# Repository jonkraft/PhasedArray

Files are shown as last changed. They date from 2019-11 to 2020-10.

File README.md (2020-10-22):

# PhasedArray
(GNU Radio 2020 Workshop presentation can be viewed here:  https://youtu.be/0hnWfTvETcU)

Phased array beamformers are very powerful! And they find applications in 5G MIMO, FMCW radar, and satellite communications. But their underlying principles and issues can be hard to intuitively grasp. But with the instructions and explanations here, you can build an easy to use system that allows you to experience the underlying math and principles of beamformers.  With this setup, you'll track an RF source, plot its beam characteristics and learn of the features integrated into modern beamformer ICs. It is a hands-on way to learn about steering angle, beam width, null locations, beam tapering, grating lobes, and beam squint.  

To get started, first read the "Phased Array Lab Build Your Own" document.  Then peruse the "Phased Array Lab" document to see what we'll be learning.  After that, please try it out and build your own.  Seeing and manipulating the beam first hand is much more informative and educational then just seeing the equations or the slides I provide of what the beam should look like.  Build it, play with it, and you'll learn a ton about this very powerful concept.

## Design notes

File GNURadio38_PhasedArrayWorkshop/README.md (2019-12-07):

These are the GNUradio flowgraphs to run the lab on.  They work great on a Raspberry Pi 3B+.  But I would recommend that you first download the entire Raspberry Pi SD card here:
https://download.analog.com/phased-array-lab/raspi.7z

It's a big file (3GB), so it'll take a while to download.  Then unzip using using 7-Zip.  Then burn it to a 32 GB (not 16, not >32GB!) micro SD card using Win32 Disk Imager (or some equivalent program).  Then place that micro SD card into your Raspberry Pi, and you will be up and running!  No other install or downloads are required.  

However, the GNU Radio files on that image may not be them most up to date.  So it's always a good idea to check the version in this "PhasedArrayLab_GNURadio" folder and make sure you have the latest.

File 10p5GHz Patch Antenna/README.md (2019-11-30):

This is an 8 element 10.5GHz Patch Antenna designed by Ozan Gurbuz.  It is for instructional or hobby use only.

This antenna can be ordered directly from PCBWAY by following this link:

  https://www.pcbway.com/project/shareproject/10_5GHz__X_Band__Patch_Antenna.html

The edge mount 50 ohm SMA connector can be ordered here:

  https://www.digikey.com/product-detail/en/BU-1420701851/314-1703-ND/9950117/?itemSeq=310517966

PCB Fabrication options are:

  Size :	171 x 60 mm
  
  Layers :	4 Layers
  
  Material :	FR-4 TG150	
  
  Thickness :	1.6 mm	
  
  Min Track/Spacing :	6/6mil
  
  Min Hole Size :	0.3	
  
  Gold fingers :	No
  
  Surface Finish :	HASL lead free	
  
  Via Process :	Tenting vias
  
  Finished Copper :	1 oz Cu (Inner Copper:1 oz)

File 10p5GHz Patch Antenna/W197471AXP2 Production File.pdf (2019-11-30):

CAM350/DFMSTREAM V 12.1 : Sun Nov 24 22:21:44 2019 - (Untitled) : BRD_OUT.gbr

CAM350/DFMSTREAM V 12.1 : Sun Nov 24 22:21:44 2019 - (Untitled) : L1_top.gbr

CAM350/DFMSTREAM V 12.1 : Sun Nov 24 22:21:44 2019 - (Untitled) : L2_inner.gbr

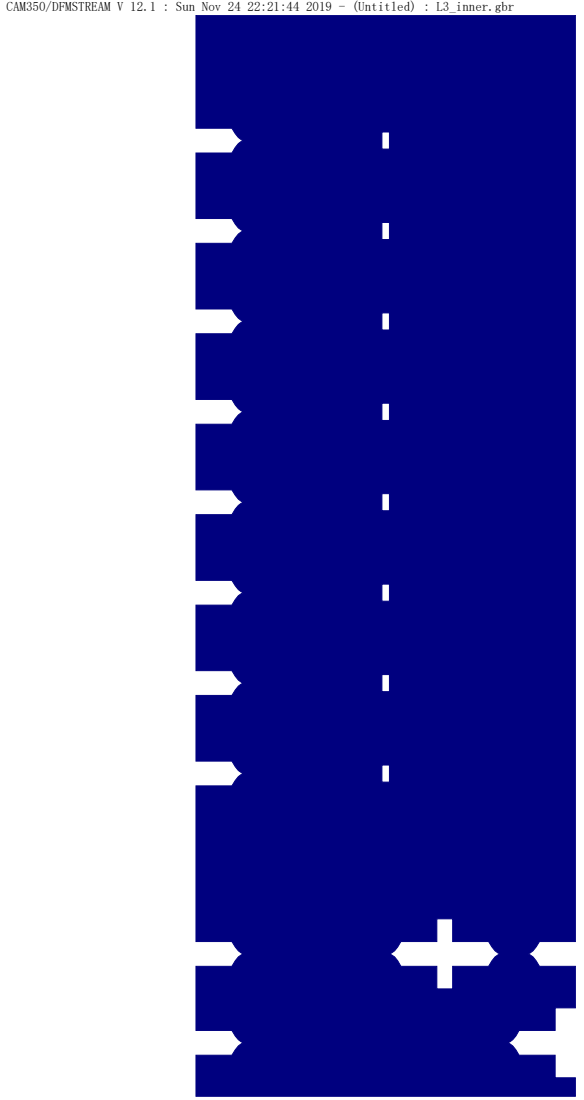
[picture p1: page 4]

CAM350/DFMSTREAM V 12.1 : Sun Nov 24 22:21:44 2019 - (Untitled) : L3_inner.gbr

CAM350/DFMSTREAM V 12.1 : Sun Nov 24 22:21:44 2019 - (Untitled) : L4_bot.gbr

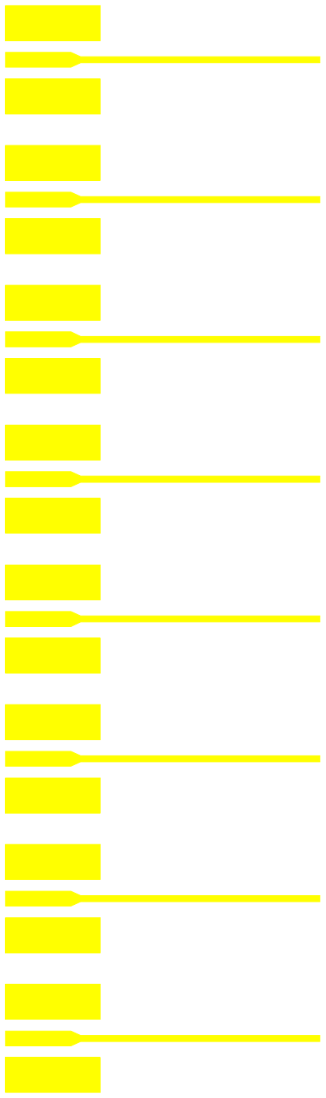
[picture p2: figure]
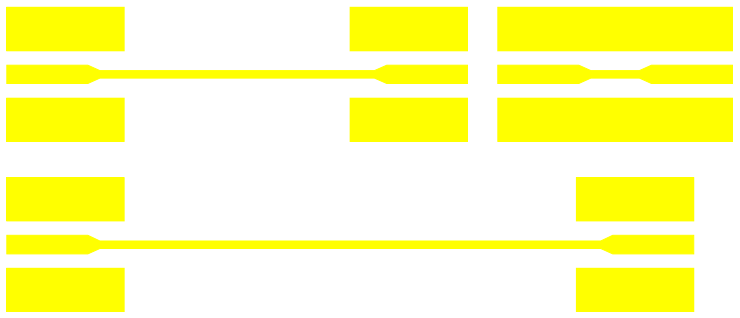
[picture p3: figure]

CAM350/DFMSTREAM V 12.1 : Sun Nov 24 22:21:44 2019 - (Untitled) : NPTH.gbr

CAM350/DFMSTREAM V 12.1 : Sun Nov 24 22:21:44 2019 - (Untitled) : SM_L1_top.gbr

CAM350/DFMSTREAM V 12.1 : Sun Nov 24 22:21:44 2019 - (Untitled) : SM_L4_bot.gbr

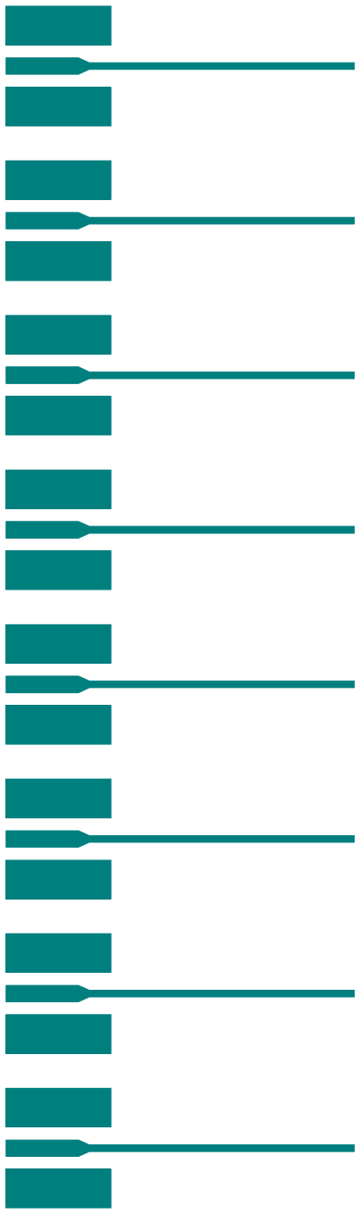
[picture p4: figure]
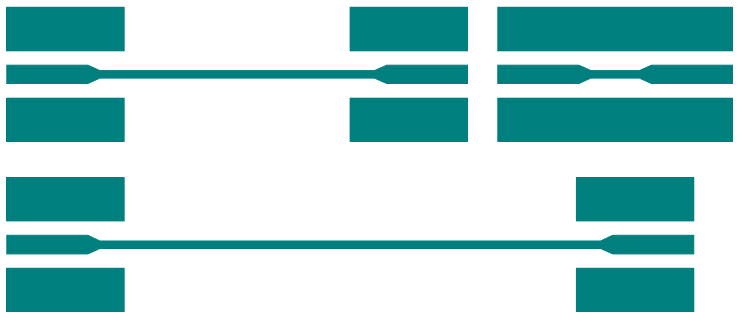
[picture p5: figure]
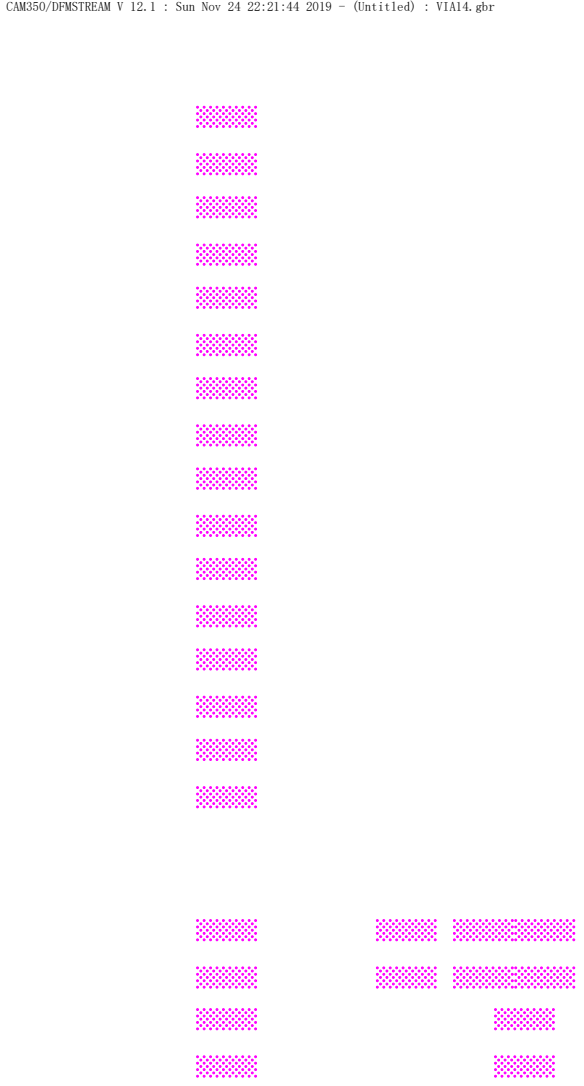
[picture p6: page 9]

CAM350/DFMSTREAM V 12.1 : Sun Nov 24 22:21:44 2019 - (Untitled) : VIA14.gbr

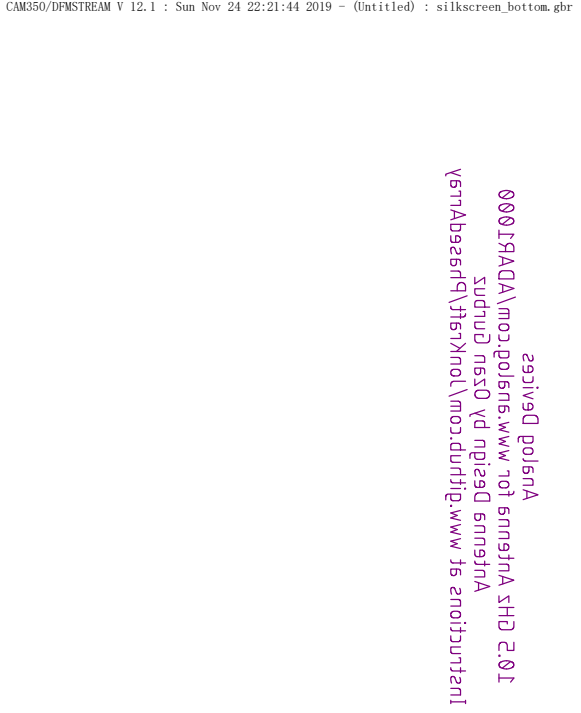
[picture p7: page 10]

CAM350/DFMSTREAM V 12.1 : Sun Nov 24 22:21:44 2019 - (Untitled) : silkscreen_bottom.gbr

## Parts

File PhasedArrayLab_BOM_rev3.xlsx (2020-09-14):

Beamformer, Mixer, and SDR
Qty | Description | Other info | Part Number | Link
1 | ADAR1000 Eval Board |  | EVAL-ADAR1000 | https://www.analog.com/en/design-center/evaluation-hardware-and-software/evaluation-boards-kits/EVAL-ADAR1000.html
1 | Pluto SDR |  | ADALM-Pluto | https://www.analog.com/en/design-center/evaluation-hardware-and-software/evaluation-boards-kits/ADALM-PLUTO.html
1 | LTC5552 Mixer |  | DC2668A | https://www.analog.com/en/design-center/evaluation-hardware-and-software/evaluation-boards-kits/dc2668a.html
1 | LT3045 3.3V LDO Board |  | DC2491A | https://www.analog.com/en/design-center/evaluation-hardware-and-software/evaluation-boards-kits/dc2491a.html
6 | 18" SMA Cable |  | 415-0033-018 | https://www.digikey.com/product-detail/en/cinch-connectivity-solutions-johnson/415-0033-018/J10114-ND/457274
1 | SMA Connector |  | ACX1240-ND | https://www.digikey.com/product-detail/en/amphenol-rf/132168/ACX1240-ND/1011917
1 | AC to DC wall wart | 5V output | PSAC05A-050L6 | https://www.digikey.com/product-detail/en/phihong-usa/PSAC05A-050L6/993-1330-ND/5418482 |  | https://www.amazon.com/gp/product/B01N7RS0NG/ref=ppx_yo_dt_b_asin_title_o09_s00?ie=UTF8&psc=1
1 | 2.1x5.5mm barrel jack wires |  |  | https://www.amazon.com/gp/product/B07CWQPPTW/ref=ppx_yo_dt_b_asin_title_o05_s00?ie=UTF8&psc=1
1 | Banana Jack | Red | 108-1082-001 | https://www.digikey.com/product-detail/en/108-1082-001/J460-ND/35155/?itemSeq=307381256
1 | Banana Jack | Black | 108-1083-001 | https://www.digikey.com/product-detail/en/108-1083-001/J461-ND/35158/?itemSeq=307381098
10 | Bumper feet for eval boards |  | SJ5746-0-ND | https://www.digikey.com/product-detail/en/3m/SJ61A1/SJ5746-0-ND/1768456
Antenna Board, RF Source, and Stand
Qty | Description | Other info | Part Number | Link
4 | CONN SMA JACK STR 50OHM EDGE MNT |  | 314-1703-ND | https://www.digikey.com/product-detail/en/BU-1420701851/314-1703-ND/9950117/?itemSeq=310517966
1 | 8 element 10.525GHz Patch Antenna |  |  | https://www.pcbway.com/project/shareproject/10_5GHz__X_Band__Patch_Antenna.html
1 | 10.525GHz RF Source |  | HB100 | https://www.amazon.com/gp/product/B00FFW4AZ4/ref=ppx_yo_dt_b_asin_title_o00_s01?ie=UTF8&psc=1
1 | Power cable for RF Source |  | AE10621-ND | https://www.digikey.com/product-detail/en/assmann-wsw-components/AK670-OE-BLACK/AE10621-ND/2391700
1 | Stand for RF Source |  |  | https://www.amazon.com/gp/product/B07JR2Q1G1/ref=ppx_yo_dt_b_asin_title_o00_s01?ie=UTF8&psc=1
1 | Adapter to hold RF Source to Stand |  |  | https://www.amazon.com/gp/product/B07RJW34WB/ref=ppx_yo_dt_b_asin_title_o00_s02?ie=UTF8&psc=1
4 | Magnet to hold antenna to stand |  | 469-1063-ND | https://www.digikey.com/product-detail/en/radial-magnet-inc/8221/469-1063-ND/5400502
Rasperry Pi and SPI Breakout Board
Qty | Description | Other info | Part Number | Link
1 | Raspberry Pi 3 or 4 |  | Rasp Pi 3 or 4
1 | Raspberry Pi breakout board for SPI |  | PROTO-001 | https://www.digikey.com/products/en?keywords=protozero | https://www.amazon.com/gp/product/B07BF8Z3HS/ref=ppx_yo_dt_b_asin_title_o00_s03?ie=UTF8&psc=1 | https://www.amazon.com/gp/product/B01M27459S/ref=ppx_yo_dt_b_search_asin_title?ie=UTF8&psc=1
2 | Polarity key for rectangular ribbon cable connector | Optional | 15040292 | https://www.digikey.com/products/en?keywords=wm1033-nd
1 | Ribbon cable connector |  | ED1543-ND | https://www.digikey.com/product-detail/en/on-shore-technology-inc/302-S101/ED1543-ND/2178422
1 | Connector for ADAR1000 eval board |  | AWP 20-7240-T | https://www.digikey.com/products/en?keywords=ae11055-nd
1 | Connector to the SPI breakout board |  | 61201023021 | https://www.digikey.com/products/en/connectors-interconnects/rectangular-connectors-free-hanging-panel-mount/316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
Full setup instructions at www.github.com/jonkraft/phasedarray

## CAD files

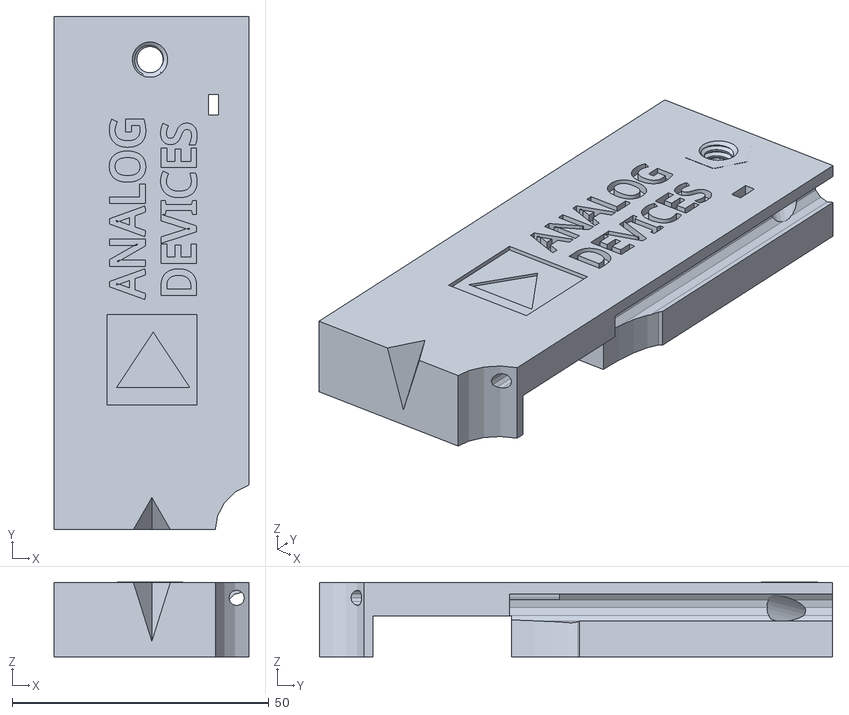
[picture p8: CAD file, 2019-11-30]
HB100_Holder.stl
38.0 x 100.0 x 14.6

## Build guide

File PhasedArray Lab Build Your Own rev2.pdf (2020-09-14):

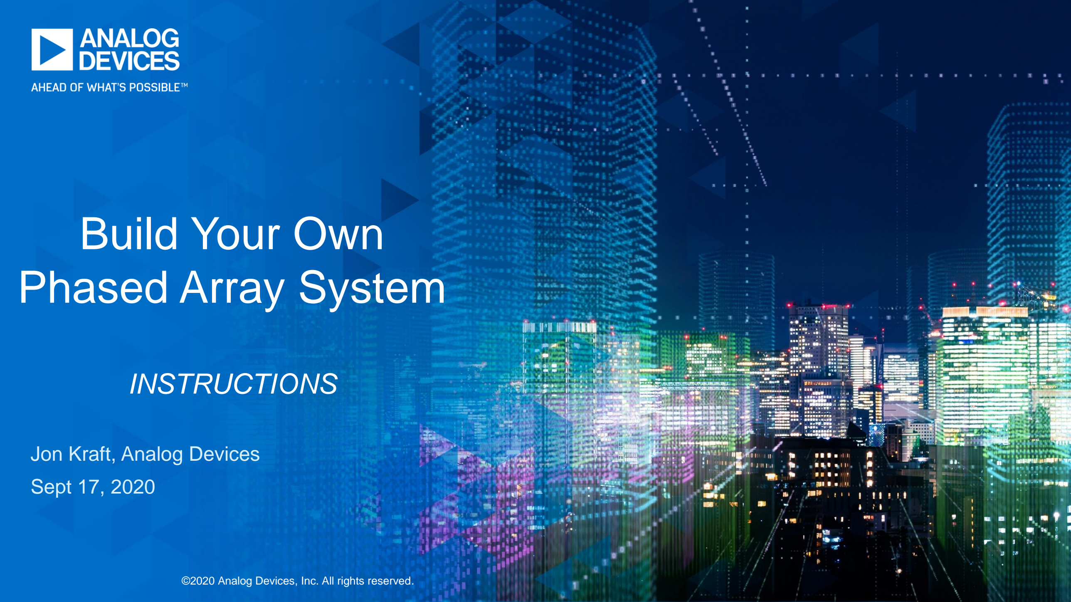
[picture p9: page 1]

# Jon Kraft, Analog Devices

# Sept 17, 2020

# Build Your Own Phased Array System

# INSTRUCTIONS

©2020 Analog Devices, Inc. All rights reserved.

# Overview of Building Instructions:

# ►Bill of Materials (BOM)

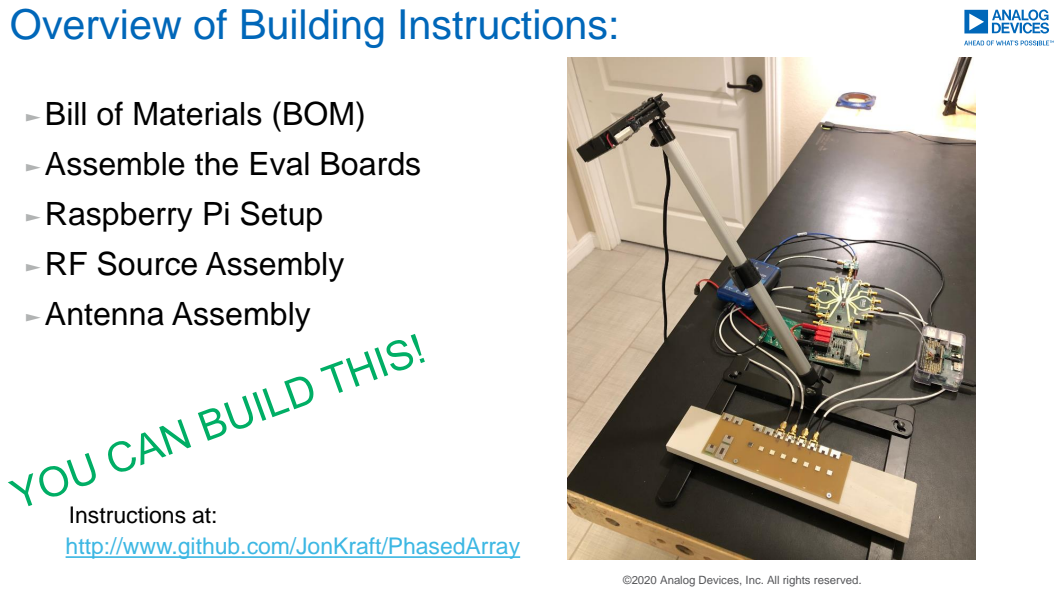
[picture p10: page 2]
©2020 Analog Devices, Inc. All rights reserved.; 14 September

►Assemble the Eval Boards
►Raspberry Pi Setup
►RF Source Assembly
►Antenna Assembly

Instructions at:
http://www.github.com/JonKraft/PhasedArray

# Simple Phased Array Setup

# - Can we build our own beamformer and see this math “Hands On”?

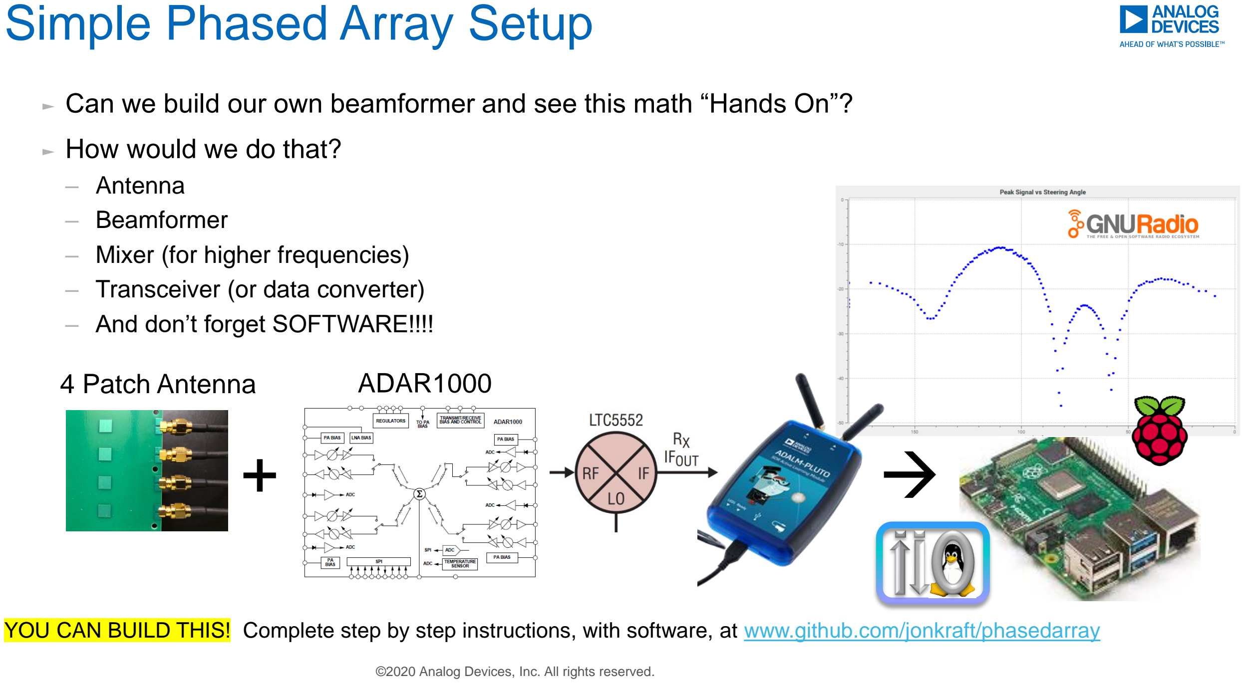
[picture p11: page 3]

### 14 September

# - How would we do that?

# – Antenna – Beamformer – Mixer (for higher frequencies) – Transceiver (or data converter) – And don’t forget SOFTWARE!!!!

3 | ©2020 Analog Devices, Inc. All rights reserved.

### 14 September

+

4 Patch Antenna | ADAR1000

YOU CAN BUILD THIS! Complete step by step instructions, with software, at www.github.com/jonkraft/phasedarray

# Simple Phased Array Setup

TX

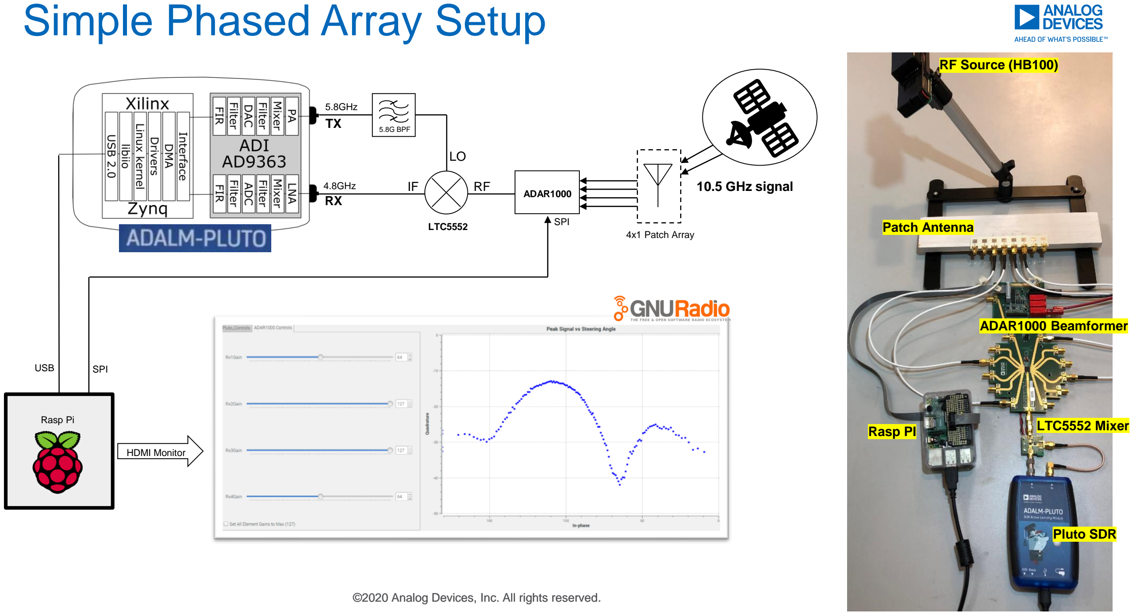
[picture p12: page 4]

4 | ©2020 Analog Devices, Inc. All rights reserved.

### 14 September

Rasp Pi

SPI

4.8GHz

LTC5552

USB

5.8GHz

5.8G BPF

HDMI Monitor

ADAR1000

4x1 Patch Array

## 10.5 GHz signal

SPI

IF

LO

RF
RX

©2020 Analog Devices, Inc. All rights reserved.

### 14 September

## ADAR1000 Beamformer

## LTC5552 Mixer

## Patch Antenna

## Pluto SDR

## Rasp PI

## RF Source (HB100)

Beamformer, Mixer, and SDR
Qty | Description | Other info | Part Number | Link
1 | ADAR1000 Eval Board | | EVAL-ADAR1000 | https://www.analog.com/en/design-center/evaluation-hardware-and-software/evaluation-boards-kits/EVAL-ADAR1000.html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
1 | Pluto SDR | | ADALM-Pluto | https://www.analog.com/en/design-center/evaluation-hardware-and-software/evaluation-boards-kits/ADALM-PLUTO.html
1 | LTC5552 Mixer | | DC2668A | https://www.analog.com/en/design-center/evaluation-hardware-and-software/evaluation-boards-kits/dc2668a.html
1 | LT3045 3.3V LDO Board | | DC2491A | https://www.analog.com/en/design-center/evaluation-hardware-and-software/evaluation-boards-kits/dc2491a.html
6 | 18" SMA Cable | 415-0033-018 | https://www.digikey.com/product-detail/en/cinch-connectivity-solutions-johnson/415-0033-018/J10114-ND/457274
1 | SMA Connector | ACX1240-ND | https://www.digikey.com/product-detail/en/amphenol-rf/132168/ACX1240-ND/1011917
1 | AC to DC wall wart | 5V output | PSAC05A-050L6 | https://www.digikey.com/product-detail/en/phihong-usa/PSAC05A-050L6/993-1330-ND/5418482

https://www.amazon.com/gp/product/B01N7RS0NG/ref=ppx_yo_dt_b_asin_title_o09_s00?ie=UTF8&psc=1 (https://www.amazon.com/gp/product/B01N7RS0NG/ref=ppx_yo_dt_b_asin_title_o09_s00?ie=UTF8&psc=1)

1 | 2.1x5.5mm barrel jack wires | | https://www.amazon.com/gp/product/B07CWQPPTW/ref=ppx_yo_dt_b_asin_title_o05_s00?ie=UTF8&psc=1
1 | Banana Jack | Red | 108-1082-001 | https://www.digikey.com/product-detail/en/108-1082-001/J460-ND/35155/?itemSeq=307381256
1 | Banana Jack | Black | 108-1083-001 | https://www.digikey.com/product-detail/en/108-1083-001/J461-ND/35158/?itemSeq=307381098
10 | Bumper feet for eval boards | SJ5746-0-ND | https://www.digikey.com/product-detail/en/3m/SJ61A1/SJ5746-0-ND/1768456
1 | Raspberry Pi 3B+ | | Rasp Pi 3 B+ | https://www.digikey.com/product-detail/en/pimoroni-ltd/PIM337/1778-1195-ND/8574322
1 | Instructions at: Raspberry Pi breakout board for SPI | PROTO-001 (http://www.github.com/JonKraft/PhasedArray) | https://www.digikey.com/products/en?keywords=protozero | | https://www.amazon.com/gp/produ | https://www.amazon.com/gp/product/B01M27
ct/B07BF8Z3HS/ref=ppx_yo_dt_b _asin_title_o00_s03?ie=UTF8&ps c=1 (https://www.amazon.com/gp/product/B07BF8Z3HS/ref=ppx_yo_dt_b_asin_title_o00_s03?ie=UTF8&psc=1)

459S/ref=ppx_yo_dt_b_search_asin_title?ie= UTF8&psc=1 (https://www.amazon.com/gp/product/B01M27459S/ref=ppx_yo_dt_b_search_asin_title?ie=UTF8&psc=1)
2 | Polarity key for rectangular ribbon cable connector | http://www.github.com/JonKraft/PhasedArray Optional | 15040292 | https://www.digikey.com/products/en?keywords=wm1033-nd
1 | Ribbon cable connector | | ED1543-ND | https://www.digikey.com/product-detail/en/on-shore-technology-inc/302-S101/ED1543-ND/2178422

Antenna Board, RF Source, and Stand
Qty | Description | Other info | Part Number | Link
4 | CONN SMA JACK STR 50OHM EDGE MNT | | 314-1703-ND | https://www.digikey.com/product-detail/en/BU-1420701851/314-1703-ND/9950117/?itemSeq=310517966
1 | 8 element 10.525GHz Patch Antenna
1 | 10.525GHz RF Source | | | https://www.amazon.com/gp/product/B00FFW4AZ4/ref=ppx_yo_dt_b_asin_title_o00_s01?ie=UTF8&psc=1
1 | Power cable for RF Source | | AE10621-ND | https://www.digikey.com/product-detail/en/assmann-wsw-components/AK670-OE-BLACK/AE10621-ND/2391700
1 | Stand for RF Source | | | https://www.amazon.com/gp/product/B07JR2Q1G1/ref=ppx_yo_dt_b_asin_title_o00_s01?ie=UTF8&psc=1
1 | Adapter to hold RF Source to Stand | | | https://www.amazon.com/gp/product/B07RJW34WB/ref=ppx_yo_dt_b_asin_title_o00_s02?ie=UTF8&psc=1
4 | Magnet to hold antenna to stand | | 469-1063-ND | https://www.digikey.com/product-detail/en/radial-magnet-inc/8221/469-1063-ND/5400502

# Bill of Materials:

# ADAR1000: 4 Channel Analog Beamformer

# ADAR1000 Features

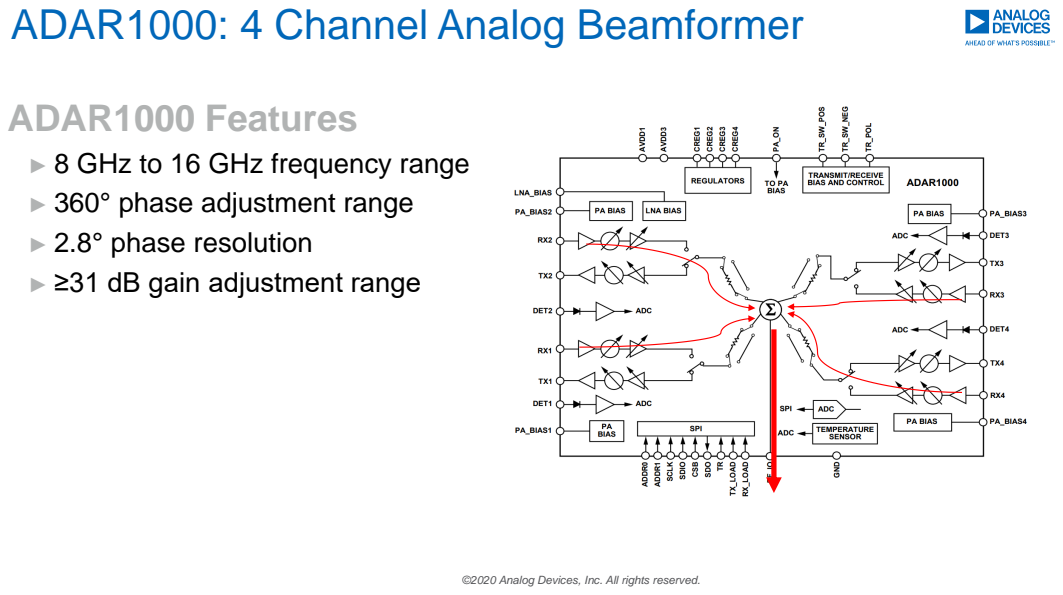
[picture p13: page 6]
14 September

► 8 GHz to 16 GHz frequency range
► 360° phase adjustment range
► 2.8° phase resolution
► ≥31 dB gain adjustment range

©2020 Analog Devices, Inc. All rights reserved.

# 10.5GHz RF Source

# ►Use the ultra fun HB100!

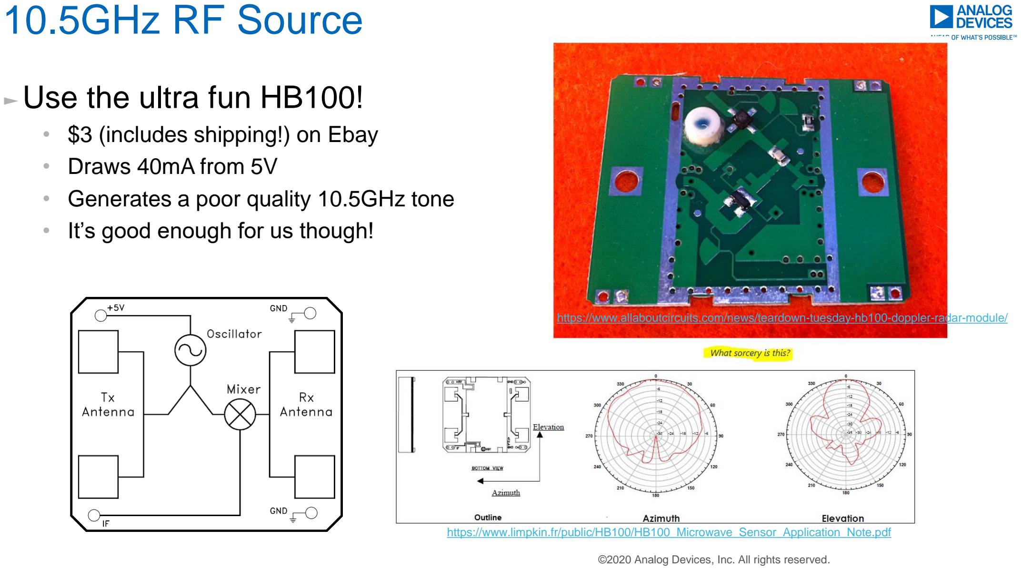
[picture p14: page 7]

7 | ©2020 Analog Devices, Inc. All rights reserved.

### 14 September

# - $3 (includes shipping!) on Ebay - Draws 40mA from 5V - Generates a poor quality 10.5GHz tone - It’s good enough for us though!

## https://www.allaboutcircuits.com/news/teardown-tuesday-hb100-doppler-radar-module/

## https://www.limpkin.fr/public/HB100/HB100_Microwave_Sensor_Application_Note.pdf

# HB100 RF Source Setup

# - Add wires to 5V and GND (see next slide)

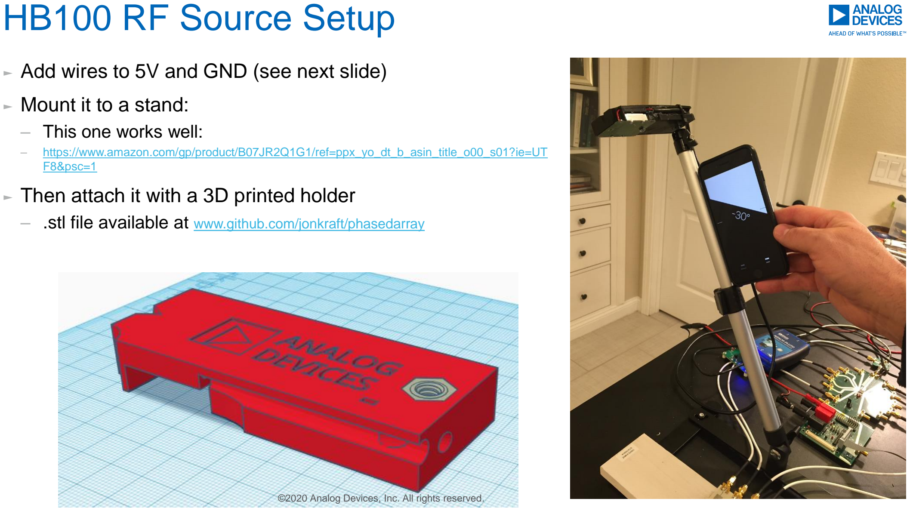
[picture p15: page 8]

# - Mount it to a stand:

# – This one works well:

– https://www.amazon.com/gp/product/B07JR2Q1G1/ref=ppx_yo_dt_b_asin_title_o00_s01?ie=UT F8&psc=1 (https://www.amazon.com/gp/product/B07JR2Q1G1/ref=ppx_yo_dt_b_asin_title_o00_s01?ie=UTF8&psc=1)

# - Then attach it with a 3D printed holder

# – .stl file available at www.github.com/jonkraft/phasedarray

©2020 Analog Devices, Inc. All rights reserved.

# Bill of Materials

9 | ©2019 Analog Devices, Inc. All rights reserved. | Dec 2019

# Bill of Materials:

Beamformer, Mixer, and SDR
Qty | Description | Other info | Part Number | Link
1 | ADAR1000 Eval Board | | EVAL-ADAR1000 | https://www.analog.com/en/design-center/evaluation-hardware-and-software/evaluation-boards-kits/EVAL-ADAR1000.html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
1 | Pluto SDR | | ADALM-Pluto | https://www.analog.com/en/design-center/evaluation-hardware-and-software/evaluation-boards-kits/ADALM-PLUTO.html
1 | LTC5552 Mixer | | DC2668A | https://www.analog.com/en/design-center/evaluation-hardware-and-software/evaluation-boards-kits/dc2668a.html
1 | LT3045 3.3V LDO Board | | DC2491A | https://www.analog.com/en/design-center/evaluation-hardware-and-software/evaluation-boards-kits/dc2491a.html
6 | 18" SMA Cable | 415-0033-018 | https://www.digikey.com/product-detail/en/cinch-connectivity-solutions-johnson/415-0033-018/J10114-ND/457274
1 | SMA Connector | ACX1240-ND | https://www.digikey.com/product-detail/en/amphenol-rf/132168/ACX1240-ND/1011917
1 | AC to DC wall wart | 5V output | PSAC05A-050L6 | https://www.digikey.com/product-detail/en/phihong-usa/PSAC05A-050L6/993-1330-ND/5418482

https://www.amazon.com/gp/product/B01N7RS0NG/ref=ppx_yo_dt_b_asin_title_o09_s00?ie=UTF8&psc=1 (https://www.amazon.com/gp/product/B01N7RS0NG/ref=ppx_yo_dt_b_asin_title_o09_s00?ie=UTF8&psc=1)

1 | 2.1x5.5mm barrel jack wires | | https://www.amazon.com/gp/product/B07CWQPPTW/ref=ppx_yo_dt_b_asin_title_o05_s00?ie=UTF8&psc=1
1 | Banana Jack | Red | 108-1082-001 | https://www.digikey.com/product-detail/en/108-1082-001/J460-ND/35155/?itemSeq=307381256
1 | Banana Jack | Black | 108-1083-001 | https://www.digikey.com/product-detail/en/108-1083-001/J461-ND/35158/?itemSeq=307381098
10 | Bumper feet for eval boards | SJ5746-0-ND | https://www.digikey.com/product-detail/en/3m/SJ61A1/SJ5746-0-ND/1768456
1 | Raspberry Pi 3 or 4 | | Rasp Pi 3 or 4
1 | Raspberry Pi breakout board for SPI | PROTO-001 | https://www.digikey.com/products/en?keywords=protozero | https://www.amazon.com/gp/produ | https://www.amazon.com/gp/product/B01M27
ct/B07BF8Z3HS/ref=ppx_yo_dt_b _asin_title_o00_s03?ie=UTF8&ps c=1 (https://www.amazon.com/gp/product/B07BF8Z3HS/ref=ppx_yo_dt_b_asin_title_o00_s03?ie=UTF8&psc=1)

459S/ref=ppx_yo_dt_b_search_asin_title?ie= UTF8&psc=1 (https://www.amazon.com/gp/product/B01M27459S/ref=ppx_yo_dt_b_search_asin_title?ie=UTF8&psc=1)
2 | Polarity key for rectangular ribbon cable connector | Optional | 15040292 | https://www.digikey.com/products/en?keywords=wm1033-nd
1 | Ribbon cable connector | | ED1543-ND | https://www.digikey.com/product-detail/en/on-shore-technology-inc/302-S101/ED1543-ND/2178422

Antenna Board, RF Source, and Stand
Qty | Description | Other info | Part Number | Link
4 | CONN SMA JACK STR 50OHM EDGE MNT | | 314-1703-ND | https://www.digikey.com/product-detail/en/BU-1420701851/314-1703-ND/9950117/?itemSeq=310517966
1 | 8 element 10.525GHz Patch Antenna
1 | 10.525GHz RF Source | | | https://www.amazon.com/gp/product/B00FFW4AZ4/ref=ppx_yo_dt_b_asin_title_o00_s01?ie=UTF8&psc=1
1 | Power cable for RF Source | | AE10621-ND | https://www.digikey.com/product-detail/en/assmann-wsw-components/AK670-OE-BLACK/AE10621-ND/2391700
1 | Stand for RF Source | | | https://www.amazon.com/gp/product/B07JR2Q1G1/ref=ppx_yo_dt_b_asin_title_o00_s01?ie=UTF8&psc=1
1 | Adapter to hold RF Source to Stand | | | https://www.amazon.com/gp/product/B07RJW34WB/ref=ppx_yo_dt_b_asin_title_o00_s02?ie=UTF8&psc=1
4 | Magnet to hold antenna to stand | | 469-1063-ND | https://www.digikey.com/product-detail/en/radial-magnet-inc/8221/469-1063-ND/5400502

# Eval Board Assembly

11 | ©2019 Analog Devices, Inc. All rights reserved. | Dec 2019

# ADAR1000 + Mixer Assembly

# - ADAR1000 Eval Board:

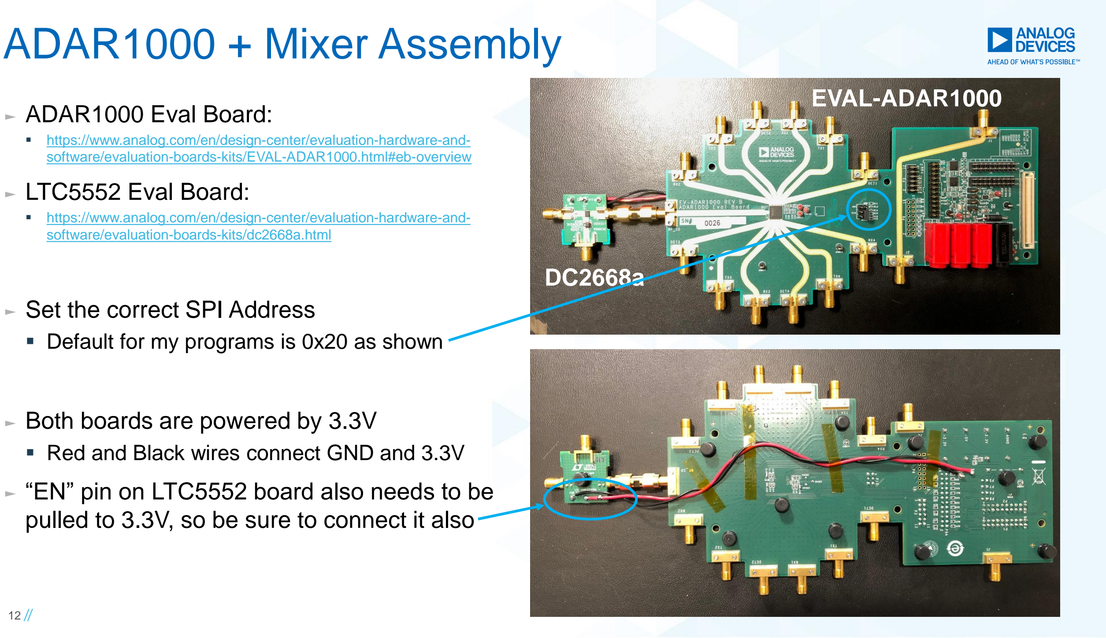
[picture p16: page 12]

## - https://www.analog.com/en/design-center/evaluation-hardware-and-

software/evaluation-boards-kits/EVAL-ADAR1000.html#eb-overview (https://www.analog.com/en/design-center/evaluation-hardware-and-software/evaluation-boards-kits/EVAL-ADAR1000.html)

# - LTC5552 Eval Board:

## - https://www.analog.com/en/design-center/evaluation-hardware-and-

software/evaluation-boards-kits/dc2668a.html (https://www.analog.com/en/design-center/evaluation-hardware-and-software/evaluation-boards-kits/dc2668a.html)

# - Set the correct SPI Address

# - Default for my programs is 0x20 as shown

# - Both boards are powered by 3.3V

# - Red and Black wires connect GND and 3.3V

# - “EN” pin on LTC5552 board also needs to be pulled to 3.3V, so be sure to connect it also

# EVAL-ADAR1000

# DC2668a

# LDO Assembly

# - Both the LTC5552 and the ADAR1000 are powered by 3.3V

- Use the ultra low noise LT3045! This is the ideal LDO for powering RF circuitry.
- https://www.analog.com/en/design-center/evaluation-hardware-and-software/evaluation-boards-kits/dc2491a.html

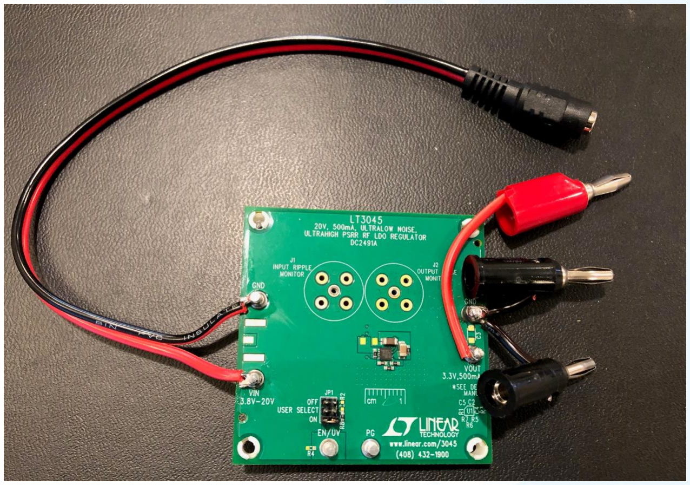
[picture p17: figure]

# Raspberry Pi Setup

14 | ©2019 Analog Devices, Inc. All rights reserved. | Dec 2019

# Raspberry Pi Setup

- Raspberry Pi 3 or 4 will work.

# - 3 Options for Install

# – Install Manually:

# - https://github.com/jonkraft/Pluto-Install-for-Raspberry-Pi

# – Use ADI-Kuiper-Linux

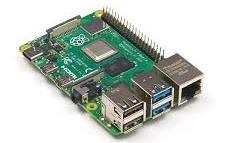
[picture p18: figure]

- Everything is preinstalled: GNURadio 3.8, IIO scope, LIBIIO,

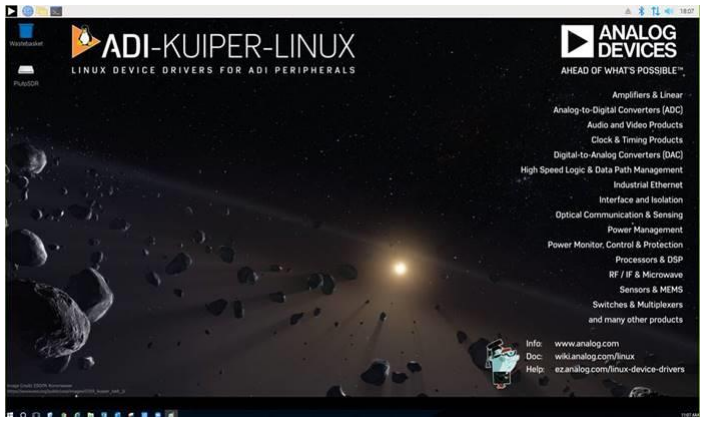
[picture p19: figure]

LIBM2K, PYADI-IIO, etc.

# - https://wiki.analog.com/resources/tools-software/linux-

software/adi-kuiper_images (https://wiki.analog.com/resources/tools-software/linux-software/adi-kuiper_images)

# – Complete out of the box, ready to go:

# - https://download.analog.com/phased-array-lab/raspi.7z - This has everything you need, including all GNU Radio 3.8

files, already loaded in there. No other installs are required,

# it’ll work out of the box!

For more info on Kuiper, please watch Mark Thoren’s GRCon 2020 “Python for the Rest of Us”

©2020 Analog Devices, Inc. All rights reserved.

# Rasp Pi SPI Breakout Board

# - Connect SPI to ADAR1000 Ribbon Cable

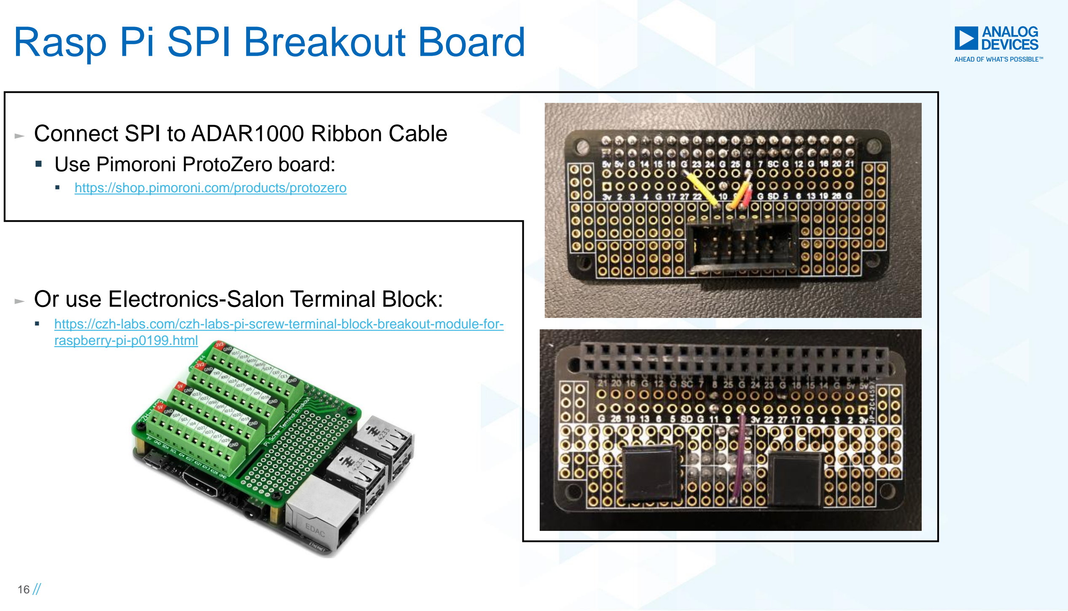
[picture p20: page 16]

# - Use Pimoroni ProtoZero board:

## - https://shop.pimoroni.com/products/protozero

# - Or use Electronics-Salon Terminal Block:

## - https://czh-labs.com/czh-labs-pi-screw-terminal-block-breakout-module-for-

raspberry-pi-p0199.html (https://czh-labs.com/czh-labs-pi-screw-terminal-block-breakout-module-for-raspberry-pi-p0199.html)

# RF Source Assembly

17 | ©2019 Analog Devices, Inc. All rights reserved. | Dec 2019

# 10.5GHz RF Source

# - Use the ultra fun HB100!

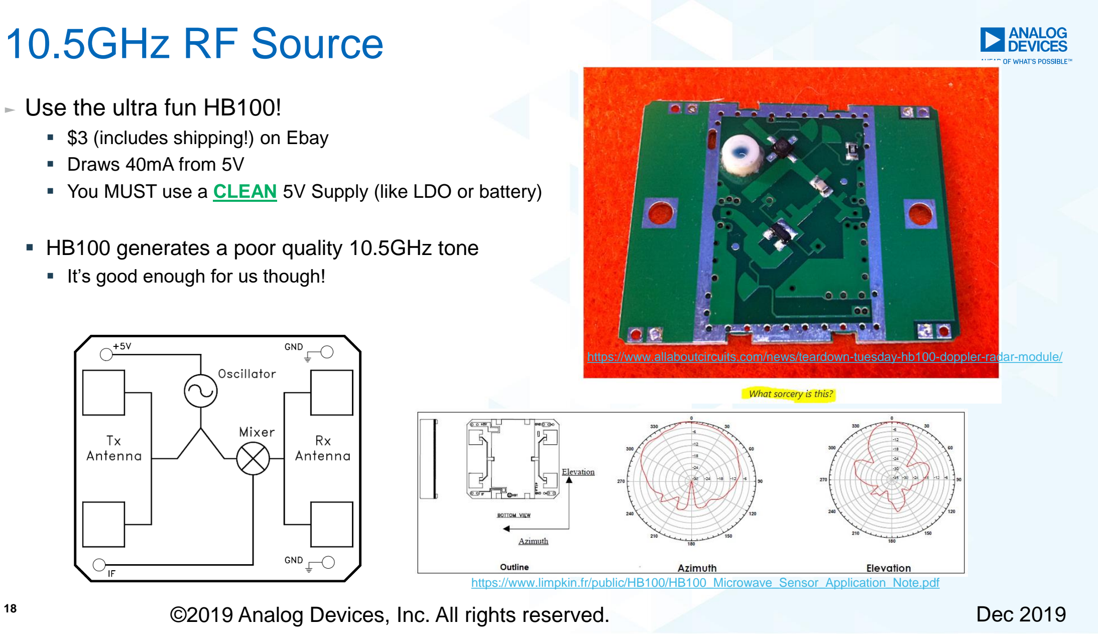
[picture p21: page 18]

# - $3 (includes shipping!) on Ebay - Draws 40mA from 5V - You MUST use a CLEAN 5V Supply (like LDO or battery)

# - HB100 generates a poor quality 10.5GHz tone

# - It’s good enough for us though!

18 | ©2019 Analog Devices, Inc. All rights reserved. | Dec 2019

## https://www.allaboutcircuits.com/news/teardown-tuesday-hb100-doppler-radar-module/

## https://www.limpkin.fr/public/HB100/HB100_Microwave_Sensor_Application_Note.pdf

# HB100 RF Source Setup

# - Add wires to 5V and GND (see next slide)

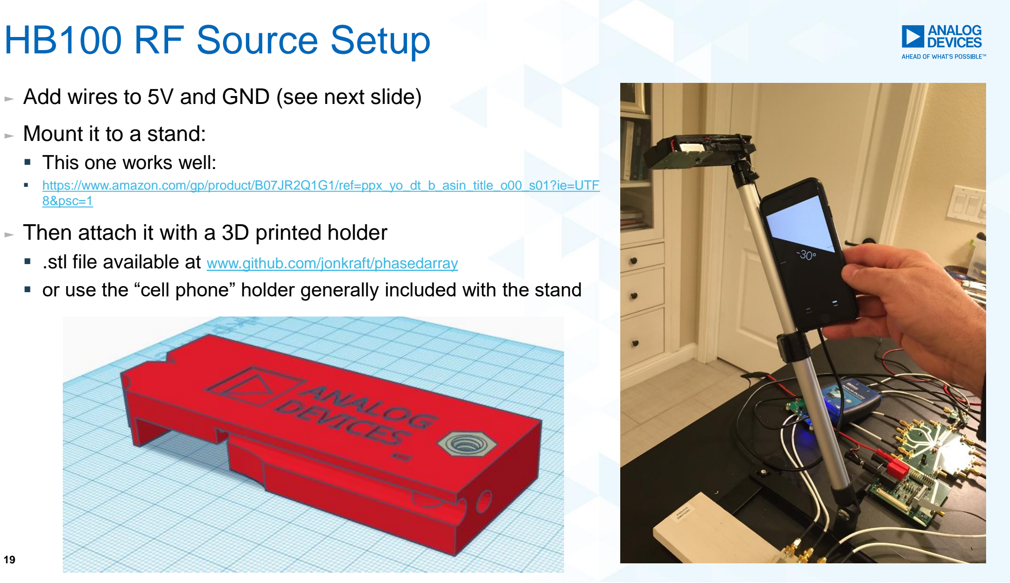
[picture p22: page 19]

# - Mount it to a stand:

# - This one works well:

## - https://www.amazon.com/gp/product/B07JR2Q1G1/ref=ppx_yo_dt_b_asin_title_o00_s01?ie=UTF

8&psc=1 (https://www.amazon.com/gp/product/B07JR2Q1G1/ref=ppx_yo_dt_b_asin_title_o00_s01?ie=UTF8&psc=1)

# - Then attach it with a 3D printed holder

# - .stl file available at www.github.com/jonkraft/phasedarray

# - or use the “cell phone” holder generally included with the stand

19

# HB100 RF Source: The Power Supply Matters!

# - HB100 must be supplied with 5V

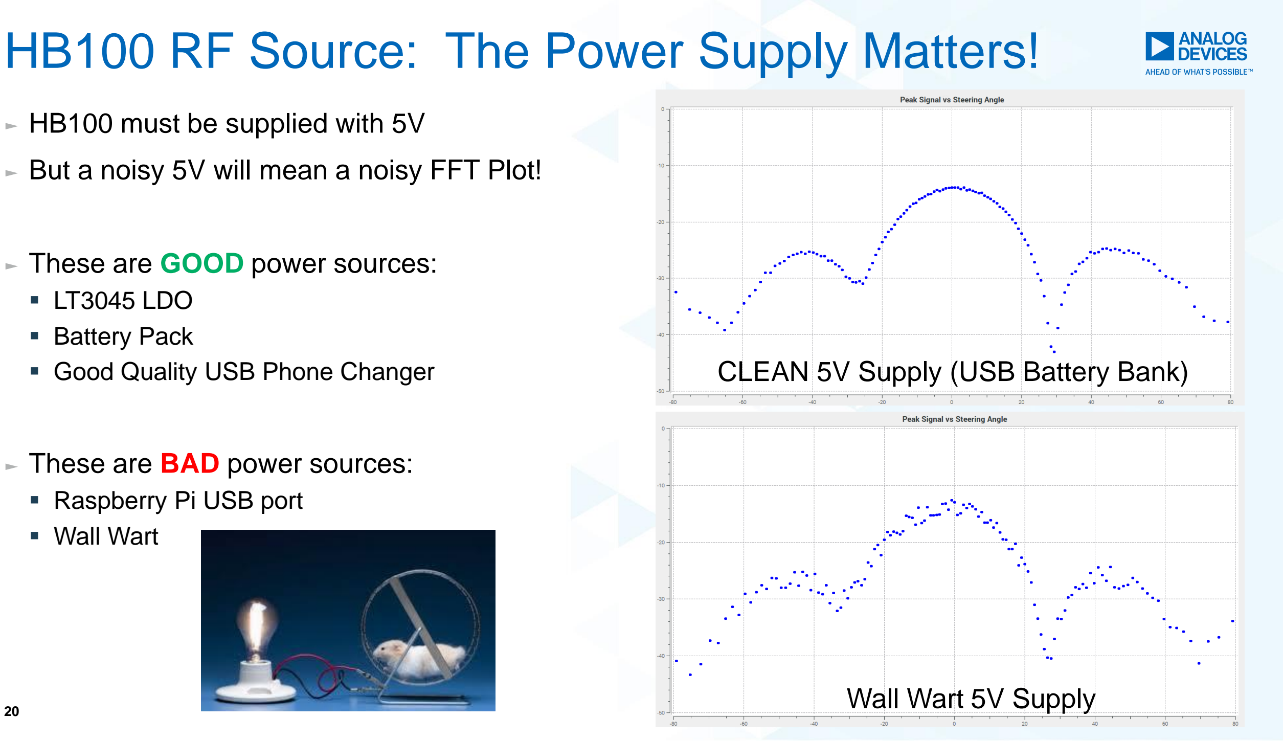
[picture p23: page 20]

# - But a noisy 5V will mean a noisy FFT Plot!

# - These are GOOD power sources:

# - LT3045 LDO - Battery Pack - Good Quality USB Phone Changer

# - These are BAD power sources:

# - Raspberry Pi USB port - Wall Wart

20

# CLEAN 5V Supply (USB Battery Bank)

# Wall Wart 5V Supply

# A MUCH Better RF Source

# - Alternatively, use an ADI Synthesizer to generate the X

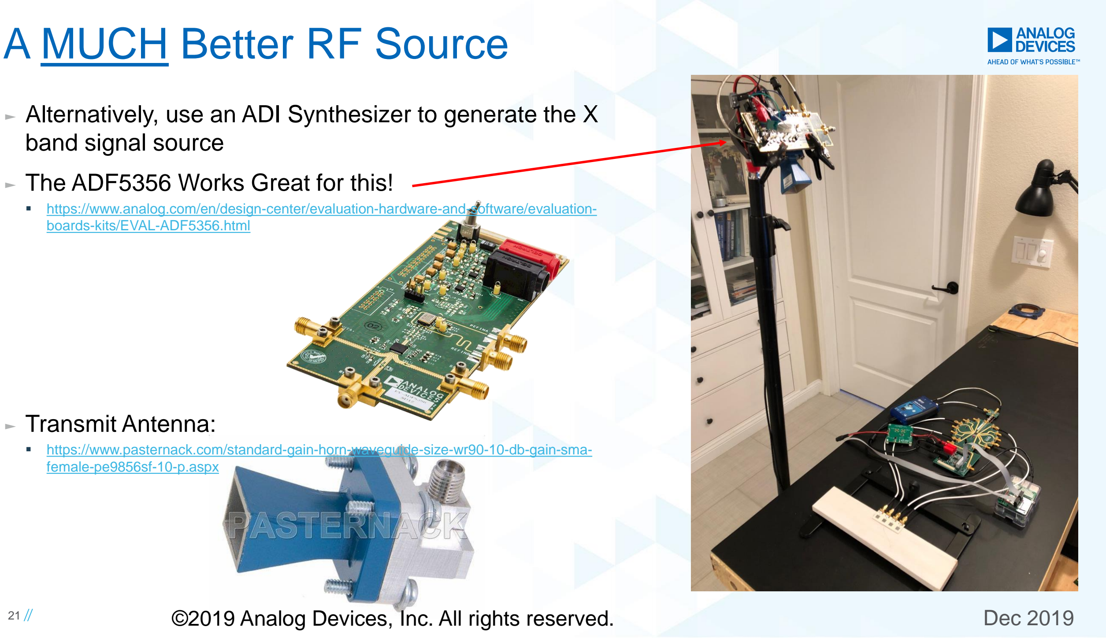
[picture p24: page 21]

# band signal source

# - The ADF5356 Works Great for this!

## - https://www.analog.com/en/design-center/evaluation-hardware-and-software/evaluation-

boards-kits/EVAL-ADF5356.html (https://www.analog.com/en/design-center/evaluation-hardware-and-software/evaluation-boards-kits/EVAL-ADF5356.html)

# - Transmit Antenna:

## - https://www.pasternack.com/standard-gain-horn-waveguide-size-wr90-10-db-gain-sma-

female-pe9856sf-10-p.aspx (https://www.pasternack.com/standard-gain-horn-waveguide-size-wr90-10-db-gain-sma-female-pe9856sf-10-p.aspx)

21 | ©2019 Analog Devices, Inc. All rights reserved. | Dec 2019

# Antenna Assembly

22 | ©2019 Analog Devices, Inc. All rights reserved. | Dec 2019

# Patch Antenna

# - A 10.5GHz patch antenna, designed for this lab by Ozan Gurbuz

- Contact your local Analog Devices sales person! They can get you one.

# - The gerber files, to make your own, are available at:

# – www.github.com/jonkraft/phasedarray

# - This antenna can also be ordered directly from PCBWAY:

– Use this link: https://www.pcbway.com/project/shareproject/10_5GHz__X_Band__Patch_Antenna.html

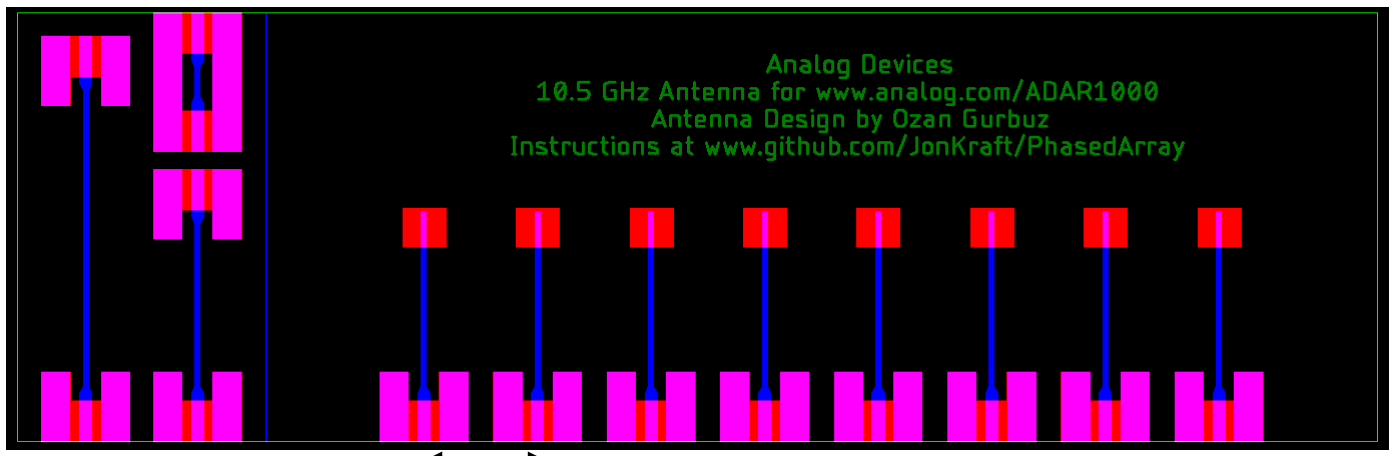
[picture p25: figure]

# - Also thanks to Kent Britain www.wa5vjb.com who made a fantastic 10GHz antenna for this

– He does amazing custom antenna designs and is very reasonably priced and approachable.

## 14.28 mm element to element spacing

©2020 Analog Devices, Inc. All rights reserved.

# Configure Pluto

24 | ©2019 Analog Devices, Inc. All rights reserved. | Dec 2019

# Upgrade Pluto

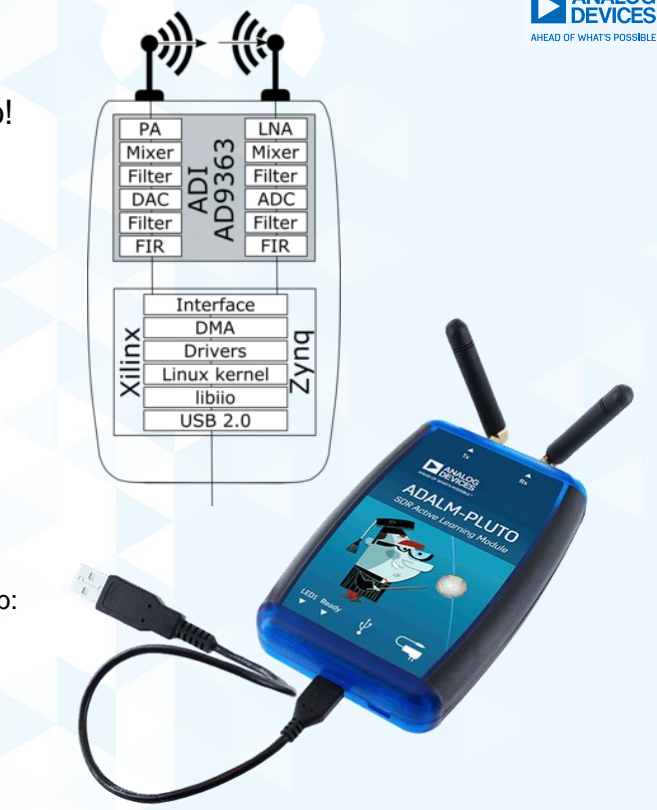
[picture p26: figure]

# - ADALM-PLUTO is an AMAZING Software Defined Radio!

## - https://wiki.analog.com/university/tools/pluto

# - Unbox it, and perform these two steps:

# - Update Firmware:

# - Download firmware here:

## - https://github.com/analogdevicesinc/plutosdr-fw/releases/latest

# - Install on Pluto:

### - https://wiki.analog.com/university/tools/pluto/users/firmware#windowsosx

# - Upgrade Pluto to higher freq range and wider BW:

# - This is required for the frequency and sample rates used in the lab:

## - https://wiki.analog.com/university/tools/pluto/users/customizing#updating_to_the_ad9364

# Put it All Together!

26 | ©2019 Analog Devices, Inc. All rights reserved. | Dec 2019

# Fully Assembled Lab Station:

## Patch Antenna

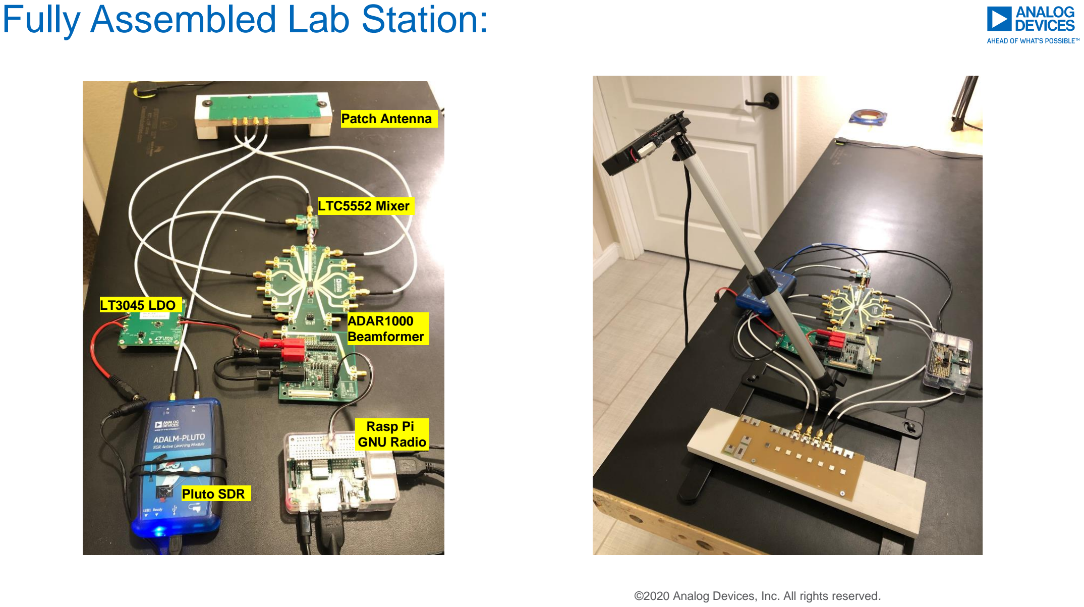
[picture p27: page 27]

27 | ©2020 Analog Devices, Inc. All rights reserved.

### 14 September

## LT3045 LDO ADAR1000 Beamformer

## LTC5552 Mixer

## Pluto SDR

## Rasp Pi GNU Radio

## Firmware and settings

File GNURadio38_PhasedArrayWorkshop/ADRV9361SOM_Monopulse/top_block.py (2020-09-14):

#!/usr/bin/env python3
# -*- coding: utf-8 -*-

#
# SPDX-License-Identifier: GPL-3.0
#
# GNU Radio Python Flow Graph
# Title: Top Block
# GNU Radio version: 3.8.1.0

from distutils.version import StrictVersion

if __name__ == '__main__':
    import ctypes
    import sys
    if sys.platform.startswith('linux'):
        try:
            x11 = ctypes.cdll.LoadLibrary('libX11.so')
            x11.XInitThreads()
        except:
            print("Warning: failed to XInitThreads()")

from PyQt5 import Qt
from gnuradio import eng_notation
from gnuradio import qtgui
import sip
from gnuradio import blocks
from gnuradio import gr
from gnuradio.filter import firdes
import sys
import signal
from argparse import ArgumentParser
from gnuradio.eng_arg import eng_float, intx
from gnuradio.qtgui import Range, RangeWidget
import ADAR1000_8_sweeper
import epy_module_1  # embedded python module

from gnuradio import qtgui

class top_block(gr.top_block, Qt.QWidget):

    def __init__(self):
        gr.top_block.__init__(self, "Top Block")
        Qt.QWidget.__init__(self)
        self.setWindowTitle("Top Block")
        qtgui.util.check_set_qss()
        try:
            self.setWindowIcon(Qt.QIcon.fromTheme('gnuradio-grc'))
        except:
            pass
        self.top_scroll_layout = Qt.QVBoxLayout()
        self.setLayout(self.top_scroll_layout)
        self.top_scroll = Qt.QScrollArea()
        self.top_scroll.setFrameStyle(Qt.QFrame.NoFrame)
        self.top_scroll_layout.addWidget(self.top_scroll)
        self.top_scroll.setWidgetResizable(True)
        self.top_widget = Qt.QWidget()
        self.top_scroll.setWidget(self.top_widget)
        self.top_layout = Qt.QVBoxLayout(self.top_widget)
        self.top_grid_layout = Qt.QGridLayout()
        self.top_layout.addLayout(self.top_grid_layout)

        self.settings = Qt.QSettings("GNU Radio", "top_block")

        try:
            if StrictVersion(Qt.qVersion()) < StrictVersion("5.0.0"):
                self.restoreGeometry(self.settings.value("geometry").toByteArray())
            else:
                self.restoreGeometry(self.settings.value("geometry"))
        except:
            pass

        ##################################################
        # Variables
        ##################################################
        self.LO_freq = LO_freq = 9500
        self.Center_freq = Center_freq = 10109
        self.BW = BW = 0
        self.variable_qtgui_label_0_0_0_0_0_0 = variable_qtgui_label_0_0_0_0_0_0 = ("%d" % (Center_freq)).rjust(16)
        self.variable_qtgui_label_0_0_0_0_0 = variable_qtgui_label_0_0_0_0_0 = ("%d" % ((Center_freq-BW))).rjust(10)
        self.variable_qtgui_label_0_0_0_0 = variable_qtgui_label_0_0_0_0 = ("%d" % (BW)).rjust(28)
        self.variable_qtgui_label_0_0_0 = variable_qtgui_label_0_0_0 = ("%d" % ((Center_freq - LO_freq))).rjust(27)
        self.variable_qtgui_label_0_0 = variable_qtgui_label_0_0 = ("%d" % (LO_freq)).rjust(32)
        self.variable_qtgui_label_0 = variable_qtgui_label_0 = ("%d" % (Center_freq)).rjust(20)
        self.samp_rate = samp_rate = 40000000
        self.Times_To_Average = Times_To_Average = 1
        self.SymmetricTaper = SymmetricTaper = 0
        self.Rx_gain = Rx_gain = 0
        self.Rx8_Cal = Rx8_Cal = 0
        self.Rx8Gain = Rx8Gain = 127
        self.Rx7_Cal = Rx7_Cal = 0
        self.Rx7Gain = Rx7Gain = 127
        self.Rx6_Cal = Rx6_Cal = 0
        self.Rx6Gain = Rx6Gain = 127
        self.Rx5_Cal = Rx5_Cal = 0
        self.Rx5Gain = Rx5Gain = 127
        self.Rx4_Cal = Rx4_Cal = 0
        self.Rx4Gain = Rx4Gain = 127
        self.Rx3_Cal = Rx3_Cal = 0
        self.Rx3Gain = Rx3Gain = 127
        self.Rx2_Cal = Rx2_Cal = 0
        self.Rx2Gain = Rx2Gain = 127
        self.Rx1_to_Rx2_Offset = Rx1_to_Rx2_Offset = 0
        self.Rx1_Cal = Rx1_Cal = 0
        self.Rx1Gain = Rx1Gain = 127
        self.IgnorePhaseCals = IgnorePhaseCals = 0
        self.BeamTaper = BeamTaper = 0

        ##################################################
        # Blocks
        ##################################################
        self.ControlTab = Qt.QTabWidget()
        self.ControlTab_widget_0 = Qt.QWidget()
        self.ControlTab_layout_0 = Qt.QBoxLayout(Qt.QBoxLayout.TopToBottom, self.ControlTab_widget_0)
        self.ControlTab_grid_layout_0 = Qt.QGridLayout()
        self.ControlTab_layout_0.addLayout(self.ControlTab_grid_layout_0)
        self.ControlTab.addTab(self.ControlTab_widget_0, 'Pluto_Controls')
        self.ControlTab_widget_1 = Qt.QWidget()
        self.ControlTab_layout_1 = Qt.QBoxLayout(Qt.QBoxLayout.TopToBottom, self.ControlTab_widget_1)
        self.ControlTab_grid_layout_1 = Qt.QGridLayout()
        self.ControlTab_layout_1.addLayout(self.ControlTab_grid_layout_1)
        self.ControlTab.addTab(self.ControlTab_widget_1, 'Gain')
        self.ControlTab_widget_2 = Qt.QWidget()
        self.ControlTab_layout_2 = Qt.QBoxLayout(Qt.QBoxLayout.TopToBottom, self.ControlTab_widget_2)
        self.ControlTab_grid_layout_2 = Qt.QGridLayout()
        self.ControlTab_layout_2.addLayout(self.ControlTab_grid_layout_2)
        self.ControlTab.addTab(self.ControlTab_widget_2, 'Phase')
        self.ControlTab_widget_3 = Qt.QWidget()
        self.ControlTab_layout_3 = Qt.QBoxLayout(Qt.QBoxLayout.TopToBottom, self.ControlTab_widget_3)
        self.ControlTab_grid_layout_3 = Qt.QGridLayout()
        self.ControlTab_layout_3.addLayout(self.ControlTab_grid_layout_3)
        self.ControlTab.addTab(self.ControlTab_widget_3, 'Bandwidth')
        self.top_grid_layout.addWidget(self.ControlTab, 0, 0, 6, 2)
        for r in range(0, 6):
            self.top_grid_layout.setRowStretch(r, 1)
        for c in range(0, 2):
            self.top_grid_layout.setColumnStretch(c, 1)
        self._Times_To_Average_range = Range(1, 50, 1, 1, 10)
        self._Times_To_Average_win = RangeWidget(self._Times_To_Average_range, self.set_Times_To_Average, 'Times_To_Average', "counter_slider", int)
        self.ControlTab_grid_layout_0.addWidget(self._Times_To_Average_win, 2, 0, 1, 2)
        for r in range(2, 3):
            self.ControlTab_grid_layout_0.setRowStretch(r, 1)
        for c in range(0, 2):
            self.ControlTab_grid_layout_0.setColumnStretch(c, 1)
        _SymmetricTaper_check_box = Qt.QCheckBox('SymmetricTaper')
        self._SymmetricTaper_choices = {True: 1, False: 0}
        self._SymmetricTaper_choices_inv = dict((v,k) for k,v in self._SymmetricTaper_choices.items())
        self._SymmetricTaper_callback = lambda i: Qt.QMetaObject.invokeMethod(_SymmetricTaper_check_box, "setChecked", Qt.Q_ARG("bool", self._SymmetricTaper_choices_inv[i]))
        self._SymmetricTaper_callback(self.SymmetricTaper)
        _SymmetricTaper_check_box.stateChanged.connect(lambda i: self.set_SymmetricTaper(self._SymmetricTaper_choices[bool(i)]))
        self.ControlTab_grid_layout_1.addWidget(_SymmetricTaper_check_box, 9, 0, 1, 1)
        for r in range(9, 10):
            self.ControlTab_grid_layout_1.setRowStretch(r, 1)
        for c in range(0, 1):
            self.ControlTab_grid_layout_1.setColumnStretch(c, 1)
        self._Rx_gain_range = Range(0, 60, 1, 0, 10)
        self._Rx_gain_win = RangeWidget(self._Rx_gain_range, self.set_Rx_gain, 'Rx_gain', "counter_slider", int)
        self.ControlTab_grid_layout_0.addWidget(self._Rx_gain_win, 1, 0, 1, 2)
        for r in range(1, 2):
            self.ControlTab_grid_layout_0.setRowStretch(r, 1)
        for c in range(0, 2):
            self.ControlTab_grid_layout_0.setColumnStretch(c, 1)
        self._Rx8_Cal_range = Range(-180, 180, 2.8125, 0, 10)
        self._Rx8_Cal_win = RangeWidget(self._Rx8_Cal_range, self.set_Rx8_Cal, 'Rx8_Cal', "counter_slider", float)
        self.ControlTab_grid_layout_2.addWidget(self._Rx8_Cal_win, 7, 0, 1, 2)
        for r in range(7, 8):
            self.ControlTab_grid_layout_2.setRowStretch(r, 1)
        for c in range(0, 2):
            self.ControlTab_grid_layout_2.setColumnStretch(c, 1)
        self._Rx8Gain_range = Range(0, 127, 1, 127, 20)
        self._Rx8Gain_win = RangeWidget(self._Rx8Gain_range, self.set_Rx8Gain, 'Rx8Gain', "counter_slider", int)
        self.ControlTab_grid_layout_1.addWidget(self._Rx8Gain_win, 7, 0, 1, 2)
        for r in range(7, 8):
            self.ControlTab_grid_layout_1.setRowStretch(r, 1)
        for c in range(0, 2):
            self.ControlTab_grid_layout_1.setColumnStretch(c, 1)
        self._Rx7_Cal_range = Range(-180, 180, 2.8125, 0, 10)
        self._Rx7_Cal_win = RangeWidget(self._Rx7_Cal_range, self.set_Rx7_Cal, 'Rx7_Cal', "counter_slider", float)
        self.ControlTab_grid_layout_2.addWidget(self._Rx7_Cal_win, 6, 0, 1, 2)
        for r in range(6, 7):
            self.ControlTab_grid_layout_2.setRowStretch(r, 1)
        for c in range(0, 2):
            self.ControlTab_grid_layout_2.setColumnStretch(c, 1)
        self._Rx7Gain_range = Range(0, 127, 1, 127, 20)
        self._Rx7Gain_win = RangeWidget(self._Rx7Gain_range, self.set_Rx7Gain, 'Rx7Gain', "counter_slider", int)
        self.ControlTab_grid_layout_1.addWidget(self._Rx7Gain_win, 6, 0, 1, 2)
        for r in range(6, 7):
            self.ControlTab_grid_layout_1.setRowStretch(r, 1)
        for c in range(0, 2):
            self.ControlTab_grid_layout_1.setColumnStretch(c, 1)
        self._Rx6_Cal_range = Range(-180, 180, 2.8125, 0, 10)
        self._Rx6_Cal_win = RangeWidget(self._Rx6_Cal_range, self.set_Rx6_Cal, 'Rx6_Cal', "counter_slider", float)
        self.ControlTab_grid_layout_2.addWidget(self._Rx6_Cal_win, 5, 0, 1, 2)
        for r in range(5, 6):
            self.ControlTab_grid_layout_2.setRowStretch(r, 1)
        for c in range(0, 2):
            self.ControlTab_grid_layout_2.setColumnStretch(c, 1)
        self._Rx6Gain_range = Range(0, 127, 1, 127, 20)
        self._Rx6Gain_win = RangeWidget(self._Rx6Gain_range, self.set_Rx6Gain, 'Rx6Gain', "counter_slider", int)
        self.ControlTab_grid_layout_1.addWidget(self._Rx6Gain_win, 5, 0, 1, 2)
        for r in range(5, 6):
            self.ControlTab_grid_layout_1.setRowStretch(r, 1)
        for c in range(0, 2):
            self.ControlTab_grid_layout_1.setColumnStretch(c, 1)
        self._Rx5_Cal_range = Range(-180, 180, 2.8125, 0, 10)
        self._Rx5_Cal_win = RangeWidget(self._Rx5_Cal_range, self.set_Rx5_Cal, 'Rx5_Cal', "counter_slider", float)
        self.ControlTab_grid_layout_2.addWidget(self._Rx5_Cal_win, 4, 0, 1, 2)
        for r in range(4, 5):
            self.ControlTab_grid_layout_2.setRowStretch(r, 1)
        for c in range(0, 2):
            self.ControlTab_grid_layout_2.setColumnStretch(c, 1)
        self._Rx5Gain_range = Range(0, 127, 1, 127, 20)
        self._Rx5Gain_win = RangeWidget(self._Rx5Gain_range, self.set_Rx5Gain, 'Rx5Gain', "counter_slider", int)
        self.ControlTab_grid_layout_1.addWidget(self._Rx5Gain_win, 4, 0, 1, 2)
        for r in range(4, 5):
            self.ControlTab_grid_layout_1.setRowStretch(r, 1)
        for c in range(0, 2):
            self.ControlTab_grid_layout_1.setColumnStretch(c, 1)
        self._Rx4_Cal_range = Range(-180, 180, 2.8125, 0, 10)
        self._Rx4_Cal_win = RangeWidget(self._Rx4_Cal_range, self.set_Rx4_Cal, 'Rx4_Cal', "counter_slider", float)
        self.ControlTab_grid_layout_2.addWidget(self._Rx4_Cal_win, 3, 0, 1, 2)
        for r in range(3, 4):
            self.ControlTab_grid_layout_2.setRowStretch(r, 1)
        for c in range(0, 2):
            self.ControlTab_grid_layout_2.setColumnStretch(c, 1)
        self._Rx4Gain_range = Range(0, 127, 1, 127, 20)
        self._Rx4Gain_win = RangeWidget(self._Rx4Gain_range, self.set_Rx4Gain, 'Rx4Gain', "counter_slider", int)
        self.ControlTab_grid_layout_1.addWidget(self._Rx4Gain_win, 3, 0, 1, 2)
        for r in range(3, 4):
            self.ControlTab_grid_layout_1.setRowStretch(r, 1)
        for c in range(0, 2):
            self.ControlTab_grid_layout_1.setColumnStretch(c, 1)
        self._Rx3_Cal_range = Range(-180, 180, 2.8125, 0, 10)
        self._Rx3_Cal_win = RangeWidget(self._Rx3_Cal_range, self.set_Rx3_Cal, 'Rx3_Cal', "counter_slider", float)
        self.ControlTab_grid_layout_2.addWidget(self._Rx3_Cal_win, 2, 0, 1, 2)
        for r in range(2, 3):
            self.ControlTab_grid_layout_2.setRowStretch(r, 1)
        for c in range(0, 2):
            self.ControlTab_grid_layout_2.setColumnStretch(c, 1)
        self._Rx3Gain_range = Range(0, 127, 1, 127, 20)
        self._Rx3Gain_win = RangeWidget(self._Rx3Gain_range, self.set_Rx3Gain, 'Rx3Gain', "counter_slider", int)
        self.ControlTab_grid_layout_1.addWidget(self._Rx3Gain_win, 2, 0, 1, 2)
        for r in range(2, 3):
            self.ControlTab_grid_layout_1.setRowStretch(r, 1)
        for c in range(0, 2):
            self.ControlTab_grid_layout_1.setColumnStretch(c, 1)
        self._Rx2_Cal_range = Range(-180, 180, 2.8125, 0, 10)
        self._Rx2_Cal_win = RangeWidget(self._Rx2_Cal_range, self.set_Rx2_Cal, 'Rx2_Cal', "counter_slider", float)
        self.ControlTab_grid_layout_2.addWidget(self._Rx2_Cal_win, 1, 0, 1, 2)
        for r in range(1, 2):
            self.ControlTab_grid_layout_2.setRowStretch(r, 1)
        for c in range(0, 2):
            self.ControlTab_grid_layout_2.setColumnStretch(c, 1)
        self._Rx2Gain_range = Range(0, 127, 1, 127, 20)
        self._Rx2Gain_win = RangeWidget(self._Rx2Gain_range, self.set_Rx2Gain, 'Rx2Gain', "counter_slider", int)
        self.ControlTab_grid_layout_1.addWidget(self._Rx2Gain_win, 1, 0, 1, 2)
        for r in range(1, 2):
            self.ControlTab_grid_layout_1.setRowStretch(r, 1)
        for c in range(0, 2):
            self.ControlTab_grid_layout_1.setColumnStretch(c, 1)
        self._Rx1_to_Rx2_Offset_range = Range(-180, 180, 2.8125, 0, 10)
        self._Rx1_to_Rx2_Offset_win = RangeWidget(self._Rx1_to_Rx2_Offset_range, self.set_Rx1_to_Rx2_Offset, 'Rx1_to_Rx2_Offset', "counter_slider", float)
        self.ControlTab_grid_layout_2.addWidget(self._Rx1_to_Rx2_Offset_win, 8, 0, 1, 2)
        for r in range(8, 9):
            self.ControlTab_grid_layout_2.setRowStretch(r, 1)
        for c in range(0, 2):
            self.ControlTab_grid_layout_2.setColumnStretch(c, 1)
        self._Rx1_Cal_range = Range(-180, 180, 2.8125, 0, 10)
        self._Rx1_Cal_win = RangeWidget(self._Rx1_Cal_range, self.set_Rx1_Cal, 'Rx1_Cal', "counter_slider", float)
        self.ControlTab_grid_layout_2.addWidget(self._Rx1_Cal_win, 0, 0, 1, 2)
        for r in range(0, 1):
            self.ControlTab_grid_layout_2.setRowStretch(r, 1)
        for c in range(0, 2):
            self.ControlTab_grid_layout_2.setColumnStretch(c, 1)
        self._Rx1Gain_range = Range(0, 127, 1, 127, 20)
        self._Rx1Gain_win = RangeWidget(self._Rx1Gain_range, self.set_Rx1Gain, 'Rx1Gain', "counter_slider", int)
        self.ControlTab_grid_layout_1.addWidget(self._Rx1Gain_win, 0, 0, 1, 2)
        for r in range(0, 1):
            self.ControlTab_grid_layout_1.setRowStretch(r, 1)
        for c in range(0, 2):
            self.ControlTab_grid_layout_1.setColumnStretch(c, 1)
        _IgnorePhaseCals_check_box = Qt.QCheckBox('Set All Phase Cals to 0 deg')
        self._IgnorePhaseCals_choices = {True: 1, False: 0}
        self._IgnorePhaseCals_choices_inv = dict((v,k) for k,v in self._IgnorePhaseCals_choices.items())
        self._IgnorePhaseCals_callback = lambda i: Qt.QMetaObject.invokeMethod(_IgnorePhaseCals_check_box, "setChecked", Qt.Q_ARG("bool", self._IgnorePhaseCals_choices_inv[i]))
        self._IgnorePhaseCals_callback(self.IgnorePhaseCals)
        _IgnorePhaseCals_check_box.stateChanged.connect(lambda i: self.set_IgnorePhaseCals(self._IgnorePhaseCals_choices[bool(i)]))
        self.ControlTab_grid_layout_2.addWidget(_IgnorePhaseCals_check_box, 9, 0, 1, 2)
        for r in range(9, 10):
            self.ControlTab_grid_layout_2.setRowStretch(r, 1)
        for c in range(0, 2):
            self.ControlTab_grid_layout_2.setColumnStretch(c, 1)
        self._Center_freq_range = Range(10000, 11000, 0.1, 10109, 10)
        self._Center_freq_win = RangeWidget(self._Center_freq_range, self.set_Center_freq, 'Signal Freq (MHz)', "counter_slider", float)
        self.ControlTab_grid_layout_0.addWidget(self._Center_freq_win, 0, 0, 1, 2)
        for r in range(0, 1):
            self.ControlTab_grid_layout_0.setRowStretch(r, 1)
        for c in range(0, 2):
            self.ControlTab_grid_layout_0.setColumnStretch(c, 1)
        _BeamTaper_check_box = Qt.QCheckBox('Set All Element Gains to Max (127)')
        self._BeamTaper_choices = {True: 1, False: 0}
        self._BeamTaper_choices_inv = dict((v,k) for k,v in self._BeamTaper_choices.items())
        self._BeamTaper_callback = lambda i: Qt.QMetaObject.invokeMethod(_BeamTaper_check_box, "setChecked", Qt.Q_ARG("bool", self._BeamTaper_choices_inv[i]))
        self._BeamTaper_callback(self.BeamTaper)
        _BeamTaper_check_box.stateChanged.connect(lambda i: self.set_BeamTaper(self._BeamTaper_choices[bool(i)]))
        self.ControlTab_grid_layout_1.addWidget(_BeamTaper_check_box, 8, 0, 1, 1)
        for r in range(8, 9):
            self.ControlTab_grid_layout_1.setRowStretch(r, 1)
        for c in range(0, 1):
            self.ControlTab_grid_layout_1.setColumnStretch(c, 1)
        self._BW_range = Range(0, 2000, 100, 0, 10)
        self._BW_win = RangeWidget(self._BW_range, self.set_BW, 'Signal BW (MHz)', "counter_slider", float)
        self.ControlTab_grid_layout_3.addWidget(self._BW_win, 0, 0, 1, 1)
        for r in range(0, 1):
            self.ControlTab_grid_layout_3.setRowStretch(r, 1)
        for c in range(0, 1):
            self.ControlTab_grid_layout_3.setColumnStretch(c, 1)
        self._variable_qtgui_label_0_0_0_0_0_0_tool_bar = Qt.QToolBar(self)

        if None:
            self._variable_qtgui_label_0_0_0_0_0_0_formatter = None
        else:
            self._variable_qtgui_label_0_0_0_0_0_0_formatter = lambda x: str(x)

        self._variable_qtgui_label_0_0_0_0_0_0_tool_bar.addWidget(Qt.QLabel('Angle Measured at (MHz)' + ": "))
        self._variable_qtgui_label_0_0_0_0_0_0_label = Qt.QLabel(str(self._variable_qtgui_label_0_0_0_0_0_0_formatter(self.variable_qtgui_label_0_0_0_0_0_0)))
        self._variable_qtgui_label_0_0_0_0_0_0_tool_bar.addWidget(self._variable_qtgui_label_0_0_0_0_0_0_label)
        self.ControlTab_grid_layout_3.addWidget(self._variable_qtgui_label_0_0_0_0_0_0_tool_bar, 6, 0, 1, 1)
        for r in range(6, 7):
            self.ControlTab_grid_layout_3.setRowStretch(r, 1)
        for c in range(0, 1):
            self.ControlTab_grid_layout_3.setColumnStretch(c, 1)
        self._variable_qtgui_label_0_0_0_0_0_tool_bar = Qt.QToolBar(self)

        if None:
            self._variable_qtgui_label_0_0_0_0_0_formatter = None
        else:
            self._variable_qtgui_label_0_0_0_0_0_formatter = lambda x: str(x)

        self._variable_qtgui_label_0_0_0_0_0_tool_bar.addWidget(Qt.QLabel('Beam Weights Calc at (MHz)' + ": "))
        self._variable_qtgui_label_0_0_0_0_0_label = Qt.QLabel(str(self._variable_qtgui_label_0_0_0_0_0_formatter(self.variable_qtgui_label_0_0_0_0_0)))
        self._variable_qtgui_label_0_0_0_0_0_tool_bar.addWidget(self._variable_qtgui_label_0_0_0_0_0_label)
        self.ControlTab_grid_layout_3.addWidget(self._variable_qtgui_label_0_0_0_0_0_tool_bar, 5, 0, 1, 1)
        for r in range(5, 6):
            self.ControlTab_grid_layout_3.setRowStretch(r, 1)
        for c in range(0, 1):
            self.ControlTab_grid_layout_3.setColumnStretch(c, 1)
        self._variable_qtgui_label_0_0_0_0_tool_bar = Qt.QToolBar(self)

        if None:
            self._variable_qtgui_label_0_0_0_0_formatter = None
        else:
            self._variable_qtgui_label_0_0_0_0_formatter = lambda x: str(x)

        self._variable_qtgui_label_0_0_0_0_tool_bar.addWidget(Qt.QLabel('Signal BW (MHz)' + ": "))
        self._variable_qtgui_label_0_0_0_0_label = Qt.QLabel(str(self._variable_qtgui_label_0_0_0_0_formatter(self.variable_qtgui_label_0_0_0_0)))
        self._variable_qtgui_label_0_0_0_0_tool_bar.addWidget(self._variable_qtgui_label_0_0_0_0_label)
        self.ControlTab_grid_layout_3.addWidget(self._variable_qtgui_label_0_0_0_0_tool_bar, 4, 0, 1, 1)
        for r in range(4, 5):
            self.ControlTab_grid_layout_3.setRowStretch(r, 1)
        for c in range(0, 1):
            self.ControlTab_grid_layout_3.setColumnStretch(c, 1)
        self._variable_qtgui_label_0_0_0_tool_bar = Qt.QToolBar(self)

        if None:
            self._variable_qtgui_label_0_0_0_formatter = None
        else:
            self._variable_qtgui_label_0_0_0_formatter = lambda x: str(x)

        self._variable_qtgui_label_0_0_0_tool_bar.addWidget(Qt.QLabel('Pluto Rx LO (MHz)' + ": "))
        self._variable_qtgui_label_0_0_0_label = Qt.QLabel(str(self._variable_qtgui_label_0_0_0_formatter(self.variable_qtgui_label_0_0_0)))
        self._variable_qtgui_label_0_0_0_tool_bar.addWidget(self._variable_qtgui_label_0_0_0_label)
        self.ControlTab_grid_layout_3.addWidget(self._variable_qtgui_label_0_0_0_tool_bar, 3, 0, 1, 1)
        for r in range(3, 4):
            self.ControlTab_grid_layout_3.setRowStretch(r, 1)
        for c in range(0, 1):
            self.ControlTab_grid_layout_3.setColumnStretch(c, 1)
        self._variable_qtgui_label_0_0_tool_bar = Qt.QToolBar(self)

        if None:
            self._variable_qtgui_label_0_0_formatter = None
        else:
            self._variable_qtgui_label_0_0_formatter = lambda x: str(x)
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

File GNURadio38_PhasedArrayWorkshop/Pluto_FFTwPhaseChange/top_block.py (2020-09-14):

#!/usr/bin/env python3
# -*- coding: utf-8 -*-

#
# SPDX-License-Identifier: GPL-3.0
#
# GNU Radio Python Flow Graph
# Title: Top Block
# GNU Radio version: 3.8.1.0

from distutils.version import StrictVersion

if __name__ == '__main__':
    import ctypes
    import sys
    if sys.platform.startswith('linux'):
        try:
            x11 = ctypes.cdll.LoadLibrary('libX11.so')
            x11.XInitThreads()
        except:
            print("Warning: failed to XInitThreads()")

from PyQt5 import Qt
from gnuradio import eng_notation
from gnuradio import qtgui
from gnuradio.filter import firdes
import sip
from gnuradio import analog
from gnuradio import gr
import sys
import signal
from argparse import ArgumentParser
from gnuradio.eng_arg import eng_float, intx
from gnuradio.qtgui import Range, RangeWidget
import epy_block_0
import iio

from gnuradio import qtgui

class top_block(gr.top_block, Qt.QWidget):

    def __init__(self):
        gr.top_block.__init__(self, "Top Block")
        Qt.QWidget.__init__(self)
        self.setWindowTitle("Top Block")
        qtgui.util.check_set_qss()
        try:
            self.setWindowIcon(Qt.QIcon.fromTheme('gnuradio-grc'))
        except:
            pass
        self.top_scroll_layout = Qt.QVBoxLayout()
        self.setLayout(self.top_scroll_layout)
        self.top_scroll = Qt.QScrollArea()
        self.top_scroll.setFrameStyle(Qt.QFrame.NoFrame)
        self.top_scroll_layout.addWidget(self.top_scroll)
        self.top_scroll.setWidgetResizable(True)
        self.top_widget = Qt.QWidget()
        self.top_scroll.setWidget(self.top_widget)
        self.top_layout = Qt.QVBoxLayout(self.top_widget)
        self.top_grid_layout = Qt.QGridLayout()
        self.top_layout.addLayout(self.top_grid_layout)

        self.settings = Qt.QSettings("GNU Radio", "top_block")

        try:
            if StrictVersion(Qt.qVersion()) < StrictVersion("5.0.0"):
                self.restoreGeometry(self.settings.value("geometry").toByteArray())
            else:
                self.restoreGeometry(self.settings.value("geometry"))
        except:
            pass

        ##################################################
        # Variables
        ##################################################
        self.Rx4_Cal = Rx4_Cal = 0
        self.Rx3_Cal = Rx3_Cal = 0
        self.Rx2_Cal = Rx2_Cal = 0
        self.Rx1_Cal = Rx1_Cal = 0
        self.Phase_Delta = Phase_Delta = 0
        self.samp_rate = samp_rate = int(40000000)
        self.TX_freq = TX_freq = 5.81
        self.RxGain = RxGain = 15
        self.Rx4 = Rx4 = ((Phase_Delta*3+Rx4_Cal) % 360)
        self.Rx3 = Rx3 = ((Phase_Delta*2+Rx3_Cal) % 360)
        self.Rx2 = Rx2 = ((Phase_Delta*1+Rx2_Cal) % 360)
        self.Rx1 = Rx1 = ((Phase_Delta*0+Rx1_Cal) % 360)
        self.Center_freq = Center_freq = 10510.0
        self.BlankSpacerToFormatTab = BlankSpacerToFormatTab = "  "

        ##################################################
        # Blocks
        ##################################################
        self.ControlTab = Qt.QTabWidget()
        self.ControlTab_widget_0 = Qt.QWidget()
        self.ControlTab_layout_0 = Qt.QBoxLayout(Qt.QBoxLayout.TopToBottom, self.ControlTab_widget_0)
        self.ControlTab_grid_layout_0 = Qt.QGridLayout()
        self.ControlTab_layout_0.addLayout(self.ControlTab_grid_layout_0)
        self.ControlTab.addTab(self.ControlTab_widget_0, 'Pluto Control')
        self.ControlTab_widget_1 = Qt.QWidget()
        self.ControlTab_layout_1 = Qt.QBoxLayout(Qt.QBoxLayout.TopToBottom, self.ControlTab_widget_1)
        self.ControlTab_grid_layout_1 = Qt.QGridLayout()
        self.ControlTab_layout_1.addLayout(self.ControlTab_grid_layout_1)
        self.ControlTab.addTab(self.ControlTab_widget_1, 'ADAR1000 Phase Control')
        self.top_grid_layout.addWidget(self.ControlTab, 7, 0, 7, 7)
        for r in range(7, 14):
            self.top_grid_layout.setRowStretch(r, 1)
        for c in range(0, 7):
            self.top_grid_layout.setColumnStretch(c, 1)
        self._RxGain_range = Range(0, 60, 1, 15, 200)
        self._RxGain_win = RangeWidget(self._RxGain_range, self.set_RxGain, 'RxGain', "counter_slider", float)
        self.ControlTab_grid_layout_0.addWidget(self._RxGain_win, 1, 0, 1, 5)
        for r in range(1, 2):
            self.ControlTab_grid_layout_0.setRowStretch(r, 1)
        for c in range(0, 5):
            self.ControlTab_grid_layout_0.setColumnStretch(c, 1)
        self._Rx4_Cal_range = Range(0, 357.1875, 2.8125, 0, 200)
        self._Rx4_Cal_win = RangeWidget(self._Rx4_Cal_range, self.set_Rx4_Cal, 'Rx4_Phase', "counter_slider", float)
        self.ControlTab_grid_layout_1.addWidget(self._Rx4_Cal_win, 4, 1, 1, 5)
        for r in range(4, 5):
            self.ControlTab_grid_layout_1.setRowStretch(r, 1)
        for c in range(1, 6):
            self.ControlTab_grid_layout_1.setColumnStretch(c, 1)
        self._Rx3_Cal_range = Range(0, 357.1875, 2.8125, 0, 200)
        self._Rx3_Cal_win = RangeWidget(self._Rx3_Cal_range, self.set_Rx3_Cal, 'Rx3_Phase', "counter_slider", float)
        self.ControlTab_grid_layout_1.addWidget(self._Rx3_Cal_win, 3, 1, 1, 5)
        for r in range(3, 4):
            self.ControlTab_grid_layout_1.setRowStretch(r, 1)
        for c in range(1, 6):
            self.ControlTab_grid_layout_1.setColumnStretch(c, 1)
        self._Rx2_Cal_range = Range(0, 357.1875, 2.8125, 0, 200)
        self._Rx2_Cal_win = RangeWidget(self._Rx2_Cal_range, self.set_Rx2_Cal, 'Rx2_Phase', "counter_slider", float)
        self.ControlTab_grid_layout_1.addWidget(self._Rx2_Cal_win, 2, 1, 1, 5)
        for r in range(2, 3):
            self.ControlTab_grid_layout_1.setRowStretch(r, 1)
        for c in range(1, 6):
            self.ControlTab_grid_layout_1.setColumnStretch(c, 1)
        self._Rx1_Cal_range = Range(0, 357.1875, 2.8125, 0, 200)
        self._Rx1_Cal_win = RangeWidget(self._Rx1_Cal_range, self.set_Rx1_Cal, 'Rx1_Phase', "counter_slider", float)
        self.ControlTab_grid_layout_1.addWidget(self._Rx1_Cal_win, 1, 1, 1, 5)
        for r in range(1, 2):
            self.ControlTab_grid_layout_1.setRowStretch(r, 1)
        for c in range(1, 6):
            self.ControlTab_grid_layout_1.setColumnStretch(c, 1)
        self._Phase_Delta_range = Range(-199.6875, 199.6875, 2.8125, 0, 200)
        self._Phase_Delta_win = RangeWidget(self._Phase_Delta_range, self.set_Phase_Delta, 'Phase_Delta', "counter_slider", float)
        self.ControlTab_grid_layout_1.addWidget(self._Phase_Delta_win, 0, 1, 1, 5)
        for r in range(0, 1):
            self.ControlTab_grid_layout_1.setRowStretch(r, 1)
        for c in range(1, 6):
            self.ControlTab_grid_layout_1.setColumnStretch(c, 1)
        self._Center_freq_range = Range(10000, 11000, 0.1, 10510.0, 10)
        self._Center_freq_win = RangeWidget(self._Center_freq_range, self.set_Center_freq, 'Signal Freq (MHz)', "counter_slider", float)
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

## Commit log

2019-11-30 10.5 GHz Patch Antenna Files
2019-11-30 3D stl model for an HB100 Holder
    [HB100_Holder.stl]
2019-11-30 Bill of Materials for the Complete Project
    [PhasedArrayLab_BOM_rev1.xlsx]
